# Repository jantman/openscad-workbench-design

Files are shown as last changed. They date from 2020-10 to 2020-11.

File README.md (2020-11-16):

# openscad-workbench-design

Openscad designs for my new workbench. This has been _very_ specifically sized to fit certain items.

## Final Build

There were some changes to the plans in my build. The only ones that are important should be noticeable in the photos.

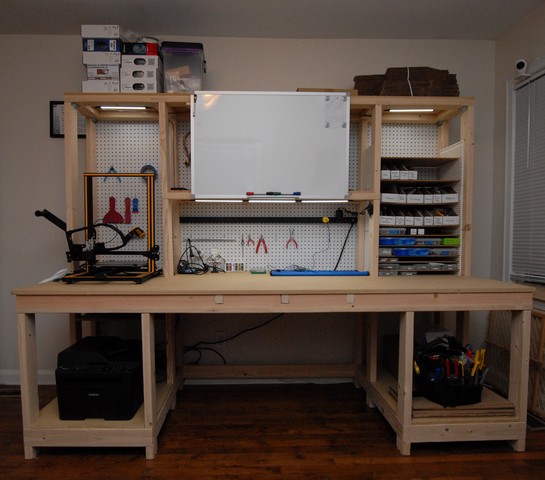
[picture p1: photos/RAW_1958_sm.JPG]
frontal photograph of finished workbench


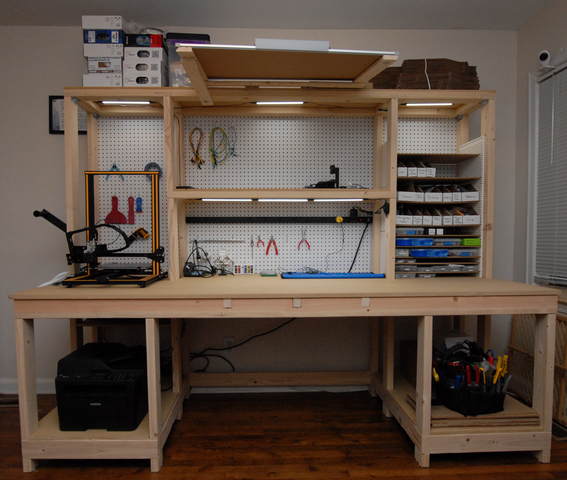
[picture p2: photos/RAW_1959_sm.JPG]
frontal photograph of finished workbench with flip-up whiteboard raised


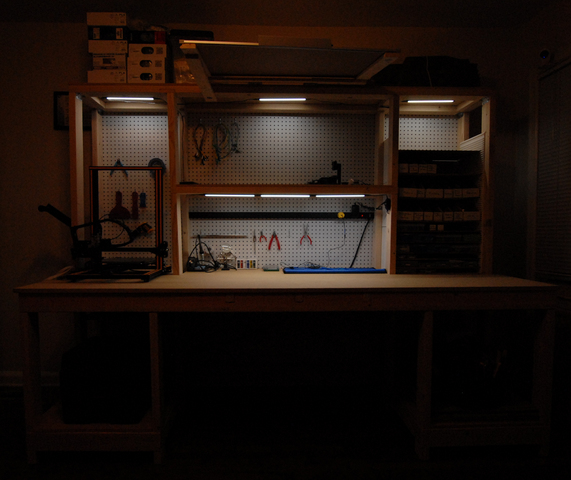
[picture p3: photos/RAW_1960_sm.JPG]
frontal photograph of finished workbench in the dark, showing build-in lights


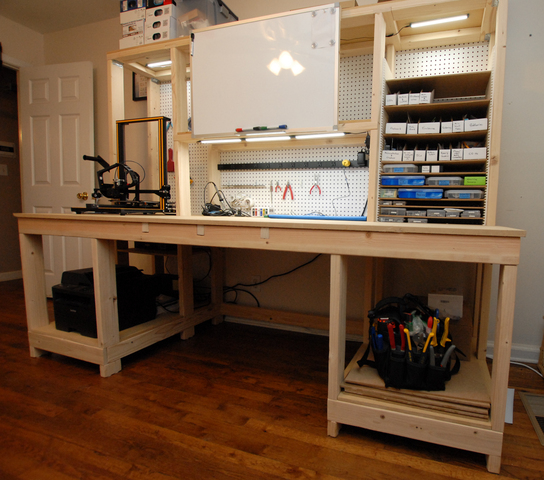
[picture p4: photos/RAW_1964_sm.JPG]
right side angle photo of finished workbench


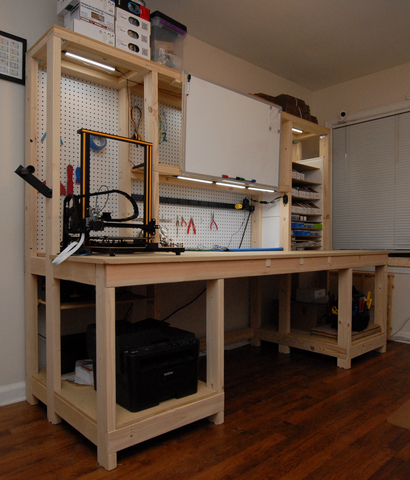
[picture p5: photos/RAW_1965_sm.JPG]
left side angle photo of finished workbench


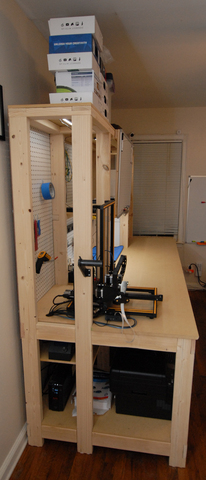
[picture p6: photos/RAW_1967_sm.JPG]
photo of left side of finished workbench


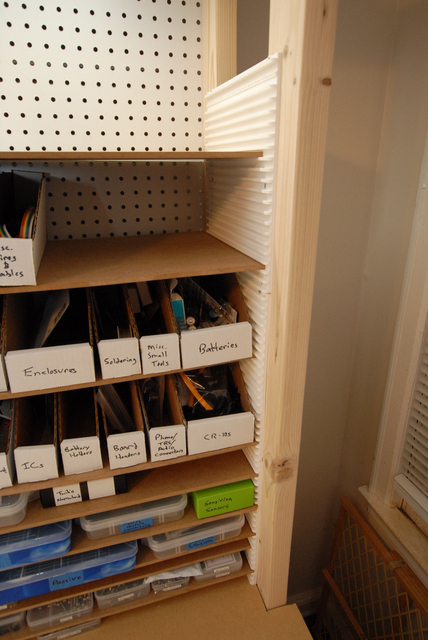
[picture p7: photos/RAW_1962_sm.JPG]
detail photo of 3d printed adjustable shelf supports


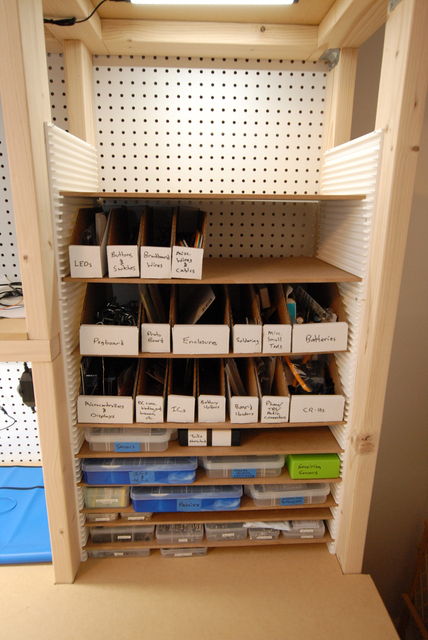
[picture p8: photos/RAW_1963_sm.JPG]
full photo of 3d printed adjustable shelf supports


## Rendered Images

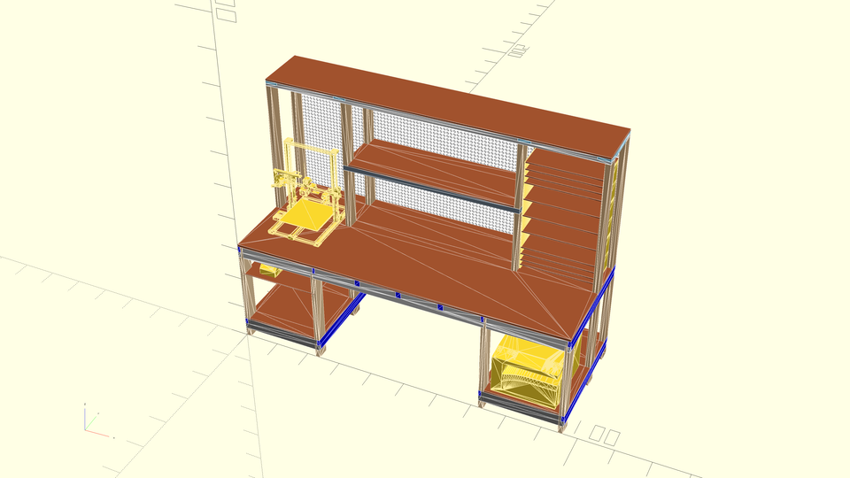
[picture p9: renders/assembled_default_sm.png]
assembled_default


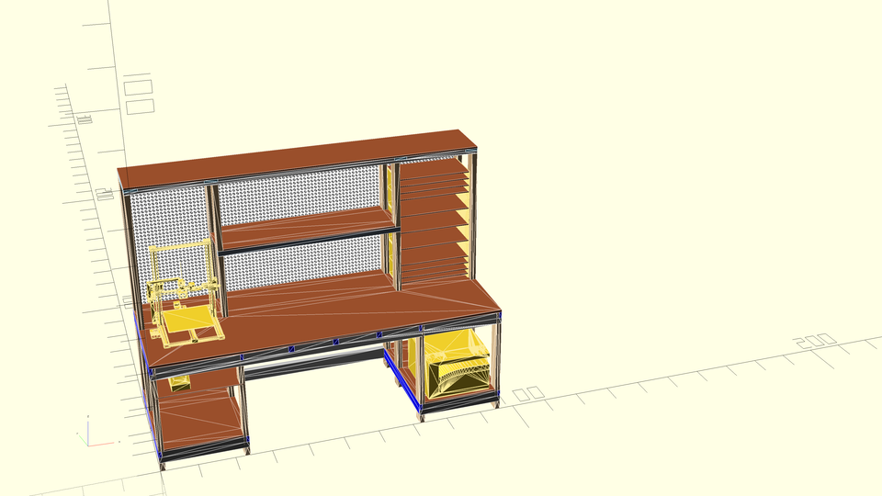
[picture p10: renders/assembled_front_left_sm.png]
assembled_front_left


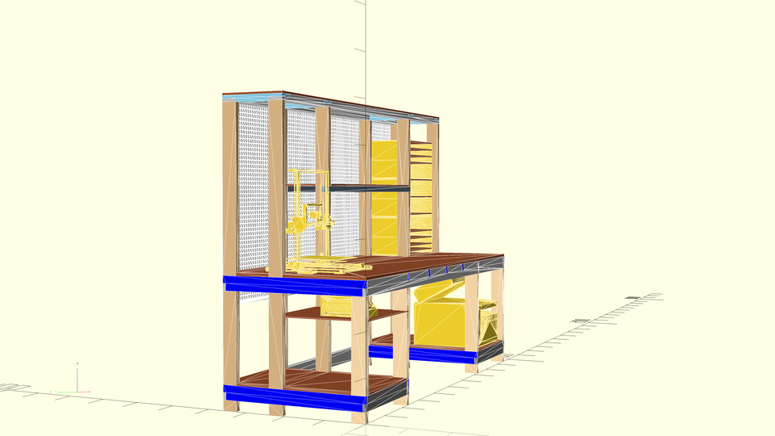
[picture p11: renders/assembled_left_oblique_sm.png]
assembled_left_oblique


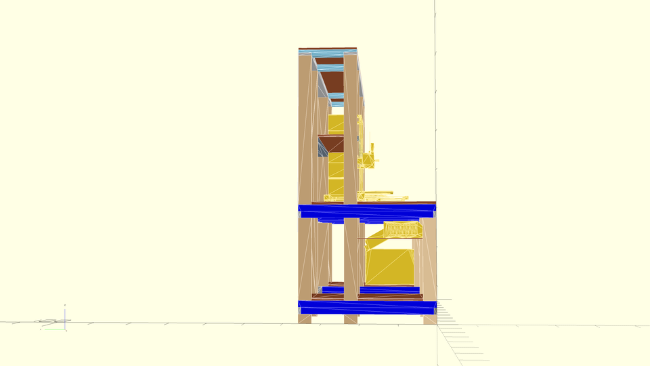
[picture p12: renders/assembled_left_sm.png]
assembled_left


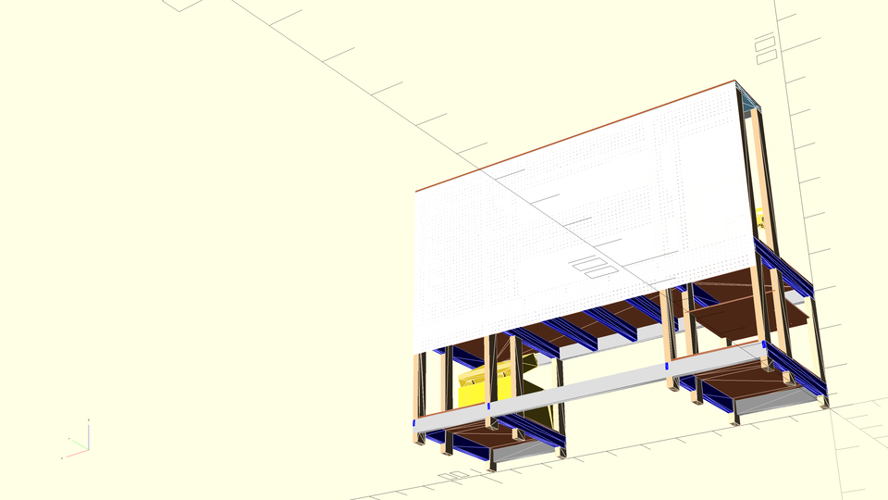
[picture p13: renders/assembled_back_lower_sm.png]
assembled_back_lower


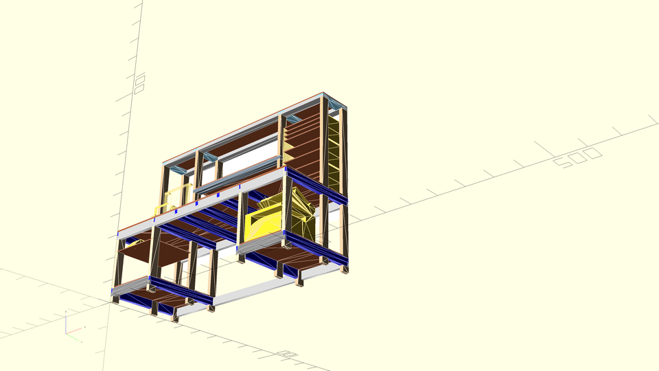
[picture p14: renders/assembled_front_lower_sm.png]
assembled_front_lower


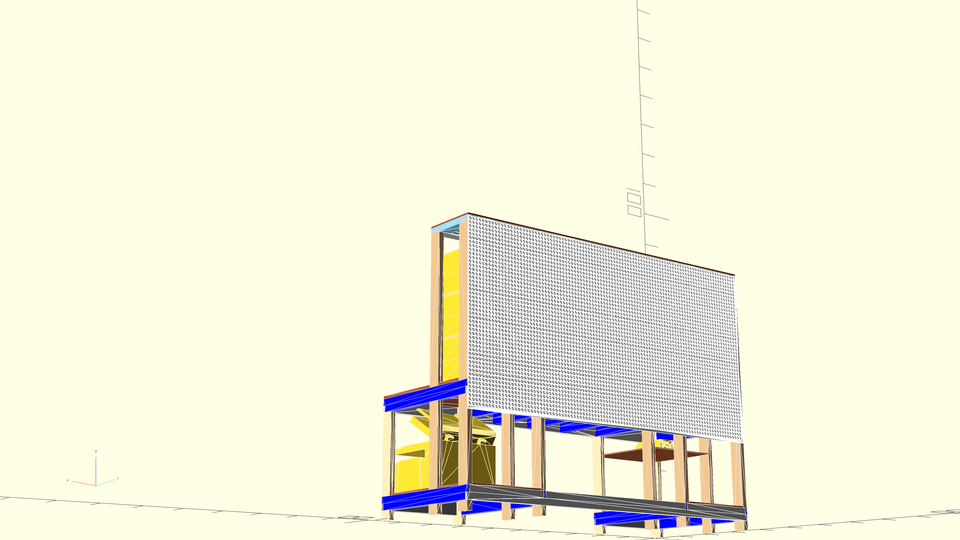
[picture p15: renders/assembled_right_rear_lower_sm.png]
assembled_right_rear_lower


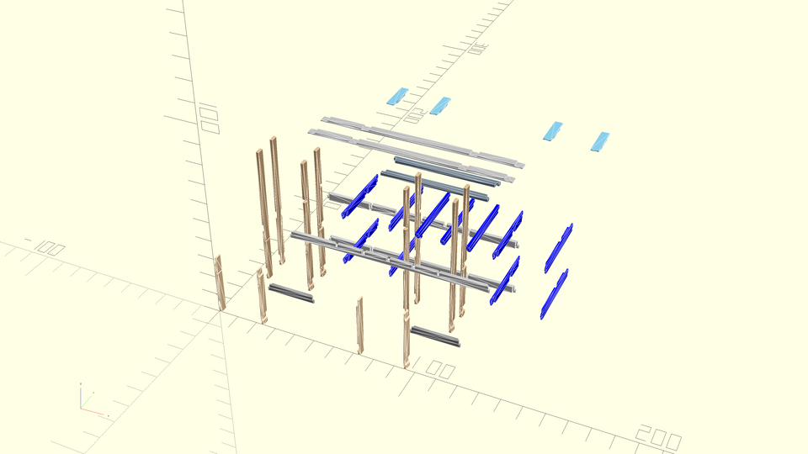
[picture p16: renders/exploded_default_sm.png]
exploded_default


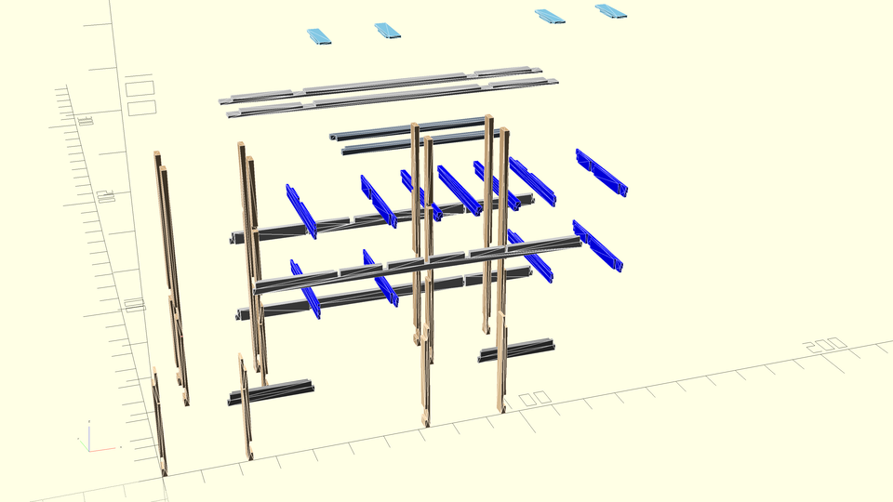
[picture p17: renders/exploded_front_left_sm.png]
exploded_front_left


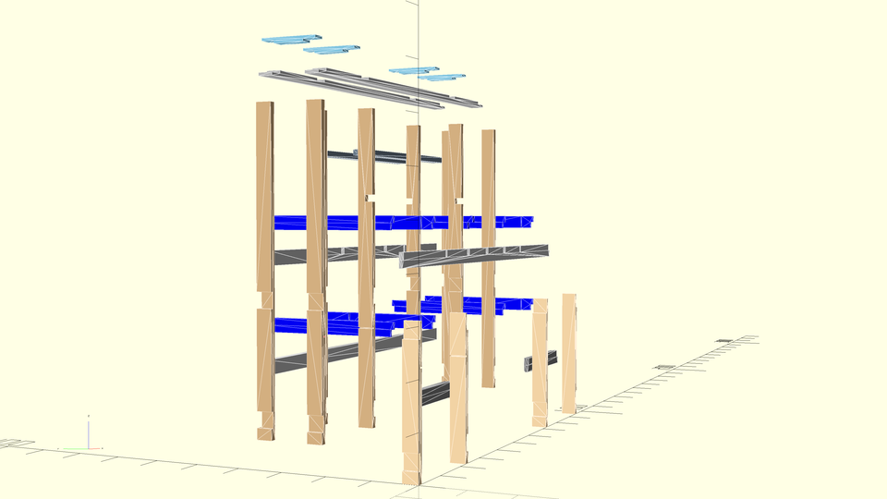
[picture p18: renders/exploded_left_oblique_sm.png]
exploded_left_oblique


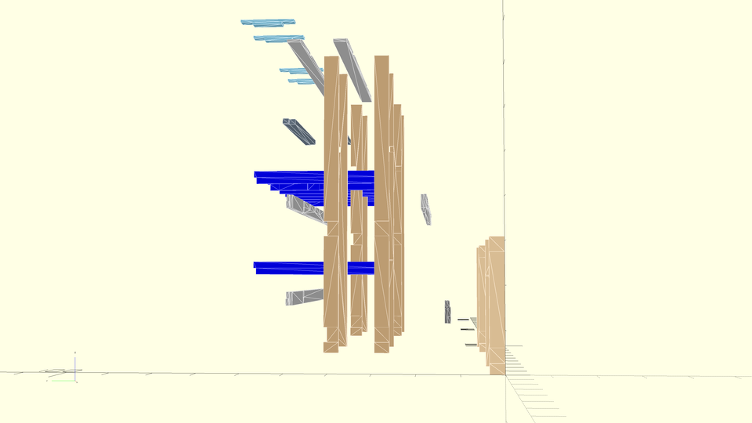
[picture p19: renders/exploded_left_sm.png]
exploded_left


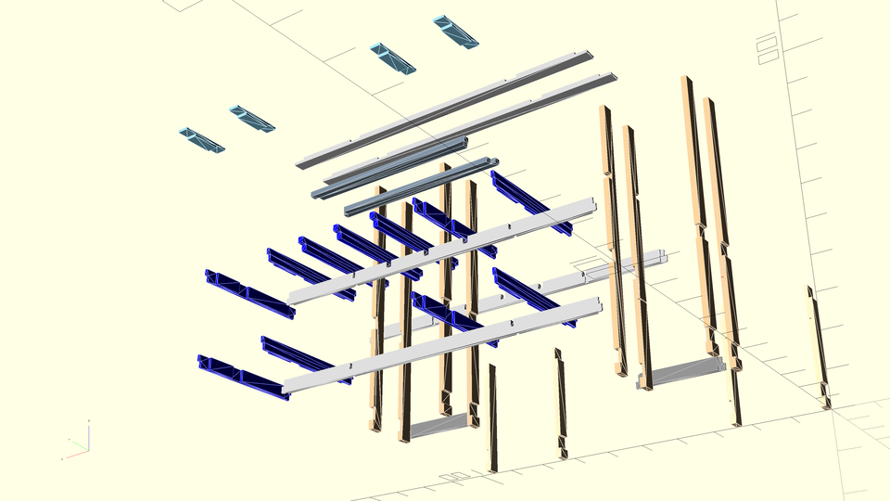
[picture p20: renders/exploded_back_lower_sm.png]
exploded_back_lower


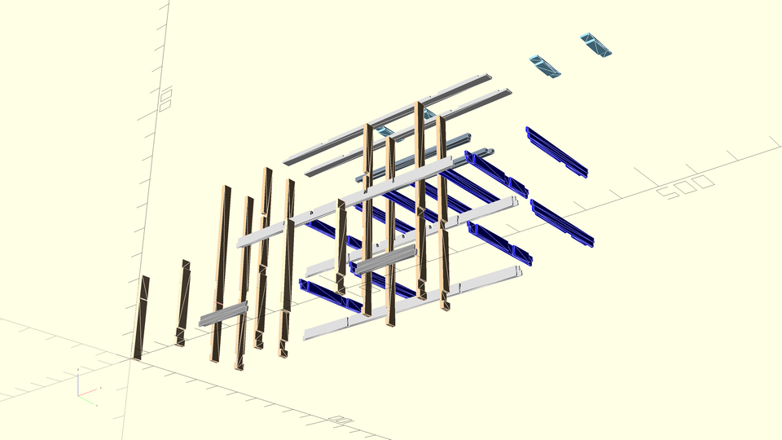
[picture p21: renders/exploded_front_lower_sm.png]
exploded_front_lower


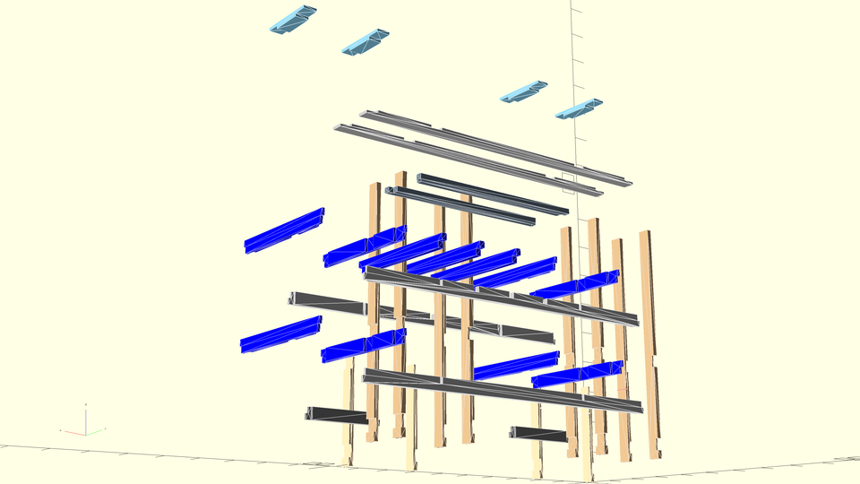
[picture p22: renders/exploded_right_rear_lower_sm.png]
exploded_right_rear_lower


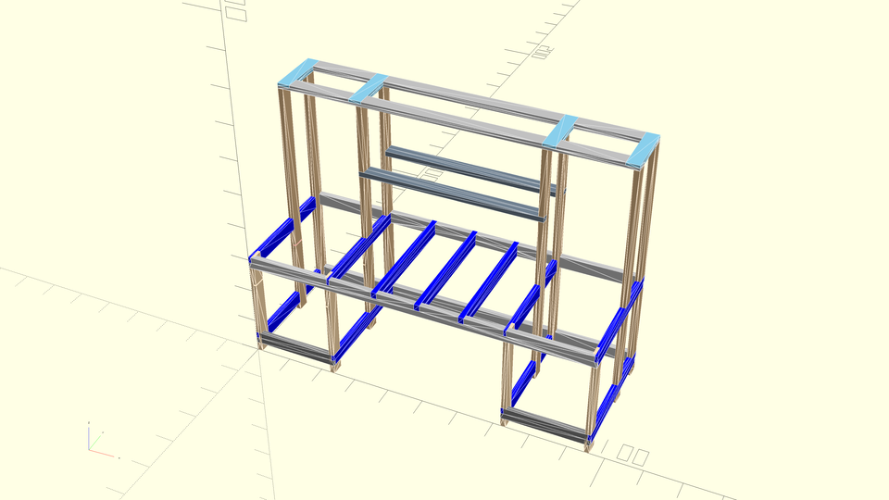
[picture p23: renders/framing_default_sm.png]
framing_default


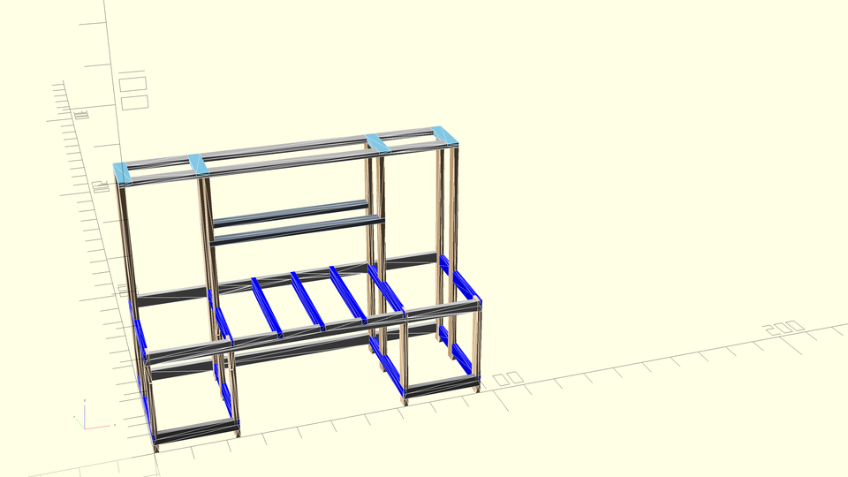
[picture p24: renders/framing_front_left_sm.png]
framing_front_left


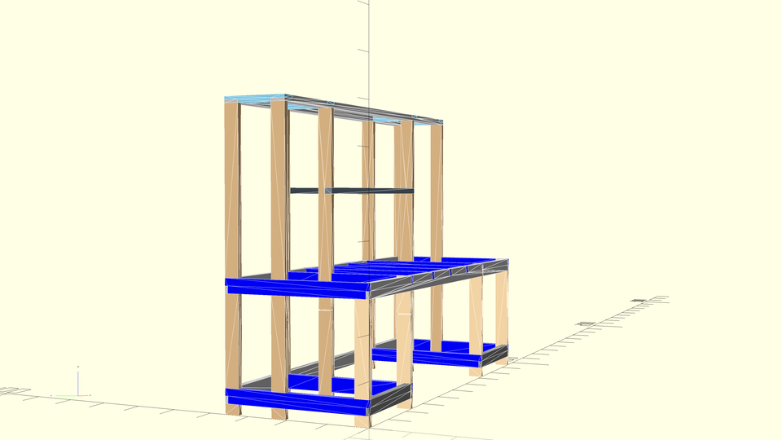
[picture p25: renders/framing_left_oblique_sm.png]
framing_left_oblique


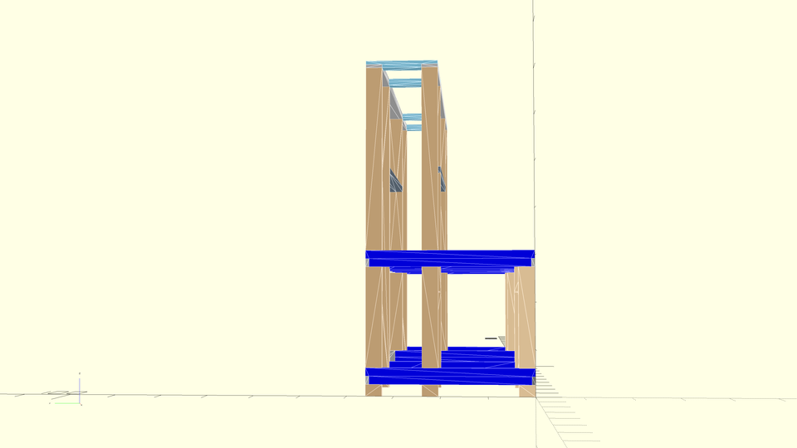
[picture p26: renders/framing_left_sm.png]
framing_left


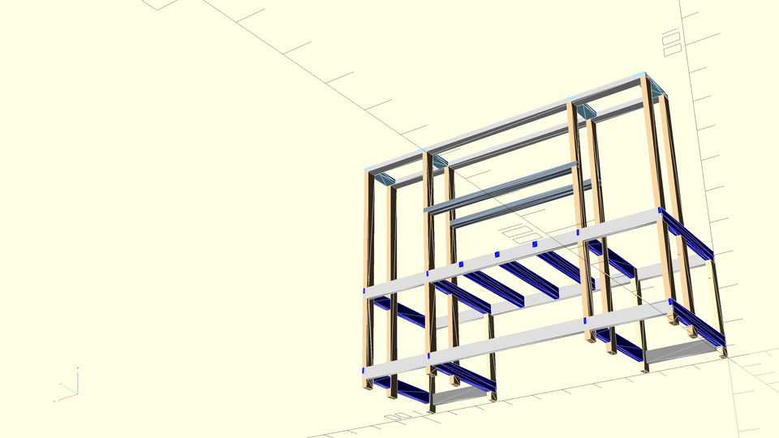
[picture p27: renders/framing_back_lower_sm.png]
framing_back_lower


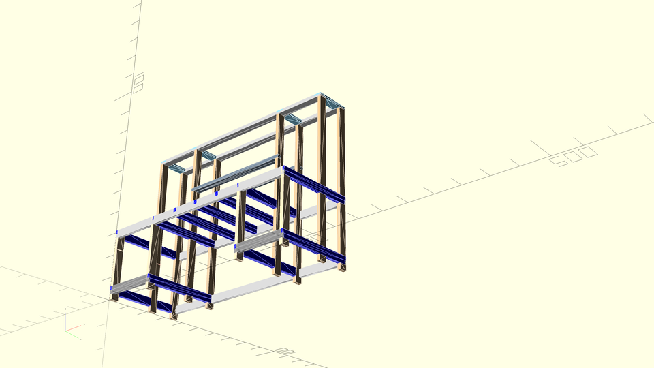
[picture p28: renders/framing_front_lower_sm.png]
framing_front_lower


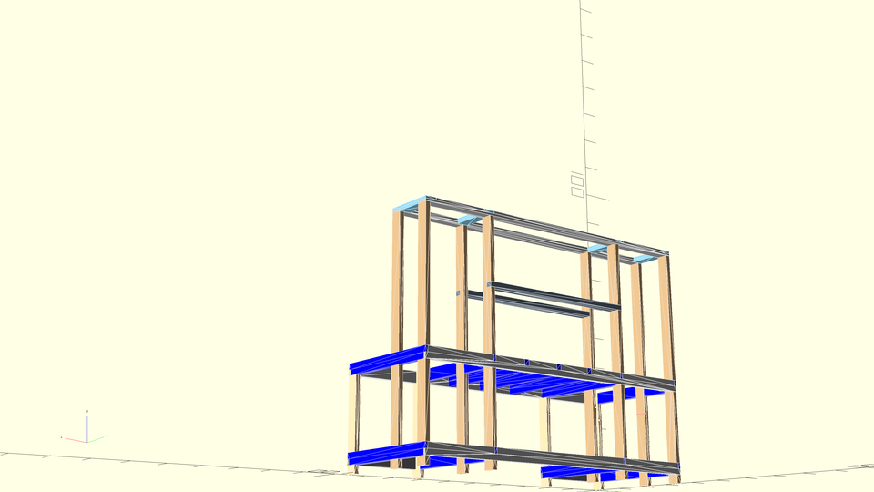
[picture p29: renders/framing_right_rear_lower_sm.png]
framing_right_rear_lower


### Shelf Supports

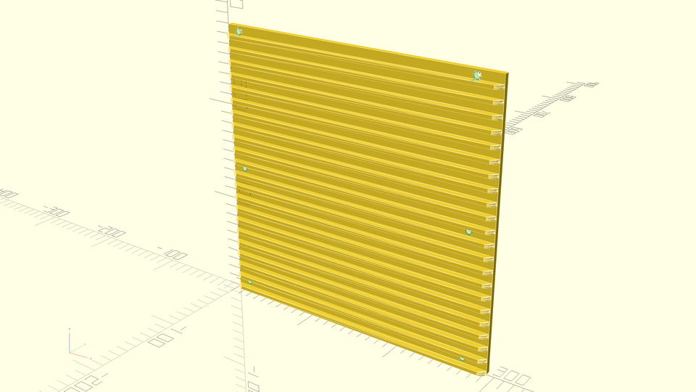
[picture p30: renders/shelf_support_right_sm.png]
shelf_support_right


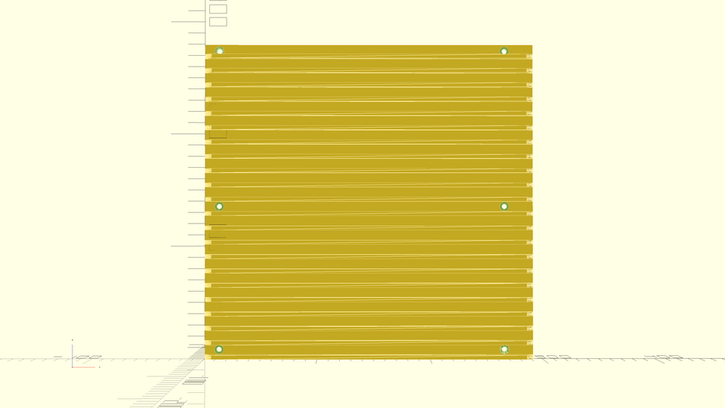
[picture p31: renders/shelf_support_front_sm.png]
shelf_support_front


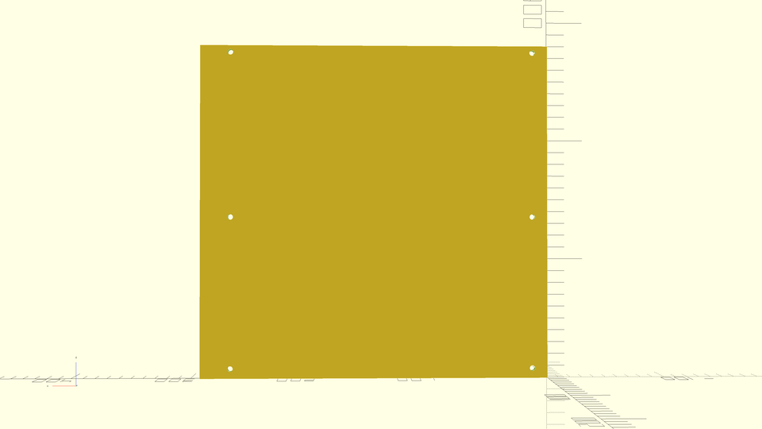
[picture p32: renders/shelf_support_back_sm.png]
shelf_support_back


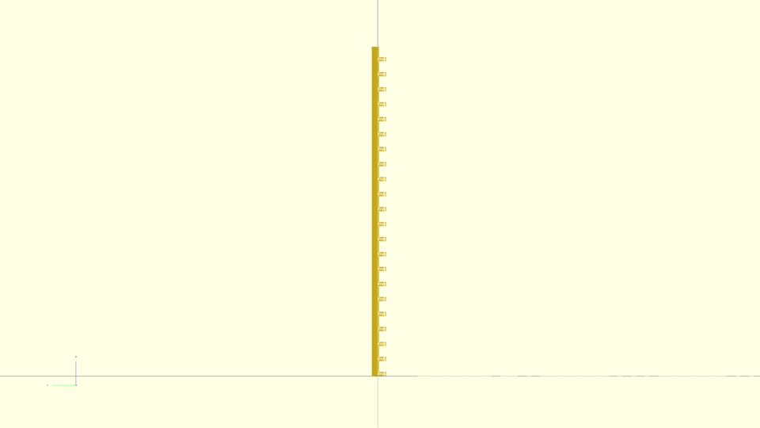
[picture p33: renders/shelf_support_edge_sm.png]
shelf_support_edge


## Parts List

* 5x 2x4x8' - long horizontal plates
* 8x 2x4x6' - rear and center legs
* 2x 2x4x51" - hutch shelf supports
* 4x 2x4x31" - front legs
* 4x 2x4x15.5" - Upper shelf supports
* 2x 2x4x2' - Lower front side short horizontal plates
* 11x 2x4x3' - Depth-wise horizontal supports (3x desktop supports, 8x lower side ties)
* 2x 2'x3' 1/2" MDF - lower shelves
* 1x 51"x15.5" 1/2" MDF - hutch shelf
* 1x 8'x3' 3/4" MDF - desktop
* 1x 8'x15.5" 1/2" MDF - top shelf
* 1x 23"x24" 1/4" MDF or plywood - left side shelf under desktop
* 1x 4'x8' pegboard, such as [this](https://www.homedepot.com/p/Pegboard-White-Panel-Common-3-16-in-x-4-ft-x-8-ft-Actual-0-155-in-x-47-7-in-x-95-7-in-486140/202189722)
* approx. 11x 12"x20.5" shelves made from [1/8" MDF](https://www.homedepot.com/p/Hardboard-Tempered-Panel-Common-1-8-in-4-ft-x-8-ft-Actual-0-115-in-x-47-7-in-x-95-7-in-832777/202189720) or [1/4" MDF](https://www.homedepot.com/p/Medium-Density-Fiberboard-Common-1-4-in-x-2-ft-x-4-ft-Actual-0-216-in-x-23-75-in-x-47-75-in-1508104/202089069) (a 4x8 sheet will make 14 shelves)
* #8 x 3/4" screws for mounting shelf supports

## Materials List

**Note:** The 1/2" MDF will fit exactly on one panel if we exclude kerf. That's what I've done, assuming the half-kerf short side will just be put on the back.

* 23x 2x4x8'
* 1x 4'x8'x3/4" MDF panel
* 1x 4'x8'x1/2" MDF panel
* 1x 2'x2'x1/4" MDF or plywood panel
* 1x 4'x8' pegboard, such as [this](https://www.homedepot.com/p/Pegboard-White-Panel-Common-3-16-in-x-4-ft-x-8-ft-Actual-0-155-in-x-47-7-in-x-95-7-in-486140/202189722)
* 1x 4'x8' [1/8" Hardboard](https://www.homedepot.com/p/Hardboard-Tempered-Panel-Common-1-8-in-4-ft-x-8-ft-Actual-0-115-in-x-47-7-in-x-95-7-in-832777/202189720) or [1/4" MDF](https://www.homedepot.com/p/Medium-Density-Fiberboard-Common-1-4-in-x-2-ft-x-4-ft-Actual-0-216-in-x-23-75-in-x-47-75-in-1508104/202089069)

## Dimensional Drawings for Fabrication and Assembly

These are tough. In short, the only way OpenSCAD can dimension drawings is if you draw, and locate, every line, arrow, and piece of text in 3D space just like any other part. I didn't know that until I'd done most of the work on this design, so I just threw in the towel on it.

[build.py](build.py) (see more below) will create ``individual_components/`` as a directory full of full-page (US Letter / 8.5x11") per-component drawings, each page containing the name, quantity, and views of all six sides. Dimensions must be added by hand, if needed. It will also create three exploded views of the framing. Because of the very poor "exploding" used, and the large number of parts, there are three exploded diagrams each showing one level of horizontal supports.

**To print** the diagrams, ensure LP is set up (``lpoptions -d PrinterName`` to set the default printer) and then just ``lp individual_components/*.png`` Since the images are already sized for the printer resolution and paper size, no scaling is needed.

## Notes

### Built Images

Running [build.py](build.py) will regenerate all rendered images in [renders/](renders/) as well as generating printable per-component views and some printable exploded diagrams (each containing a subsection of the full project, for ease of use).

### Dependencies

This code currently depends on a few STL files from another repository of mine. Rather than pull in the whole repository, which is quite large, I've included ``get_deps.sh`` which downloads the necessary files from GitHub.

### render function

According to [OpenSCAD User Manual/First Steps/Changing the color of an object - Wikibooks, open books for an open world](https://en.wikibooks.org/wiki/OpenSCAD_User_Manual/First_Steps/Changing_the_color_of_an_object) and [this mailing list post](http://forum.openscad.org/Color-in-Compile-and-Render-mode-tp4637p4639.html), color doesn't work in rendered mode, only preview. That was the case in 2013 and, as far as I can tell, is still the case in 2020. So, we can't use rendered mode, we can only use preview, because the colors are actually important.

However, in preview mode, there are usually serious issues with z-fighting between components. The fix for this seems to be to wrap each component in a [render function](https://en.wikibooks.org/wiki/OpenSCAD_User_Manual/Other_Language_Features#Render).

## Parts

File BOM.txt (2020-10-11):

      1 ECHO: "BOM ITEM: desktop width=96 depth=36 thickness=0.75"
      1 ECHO: "BOM ITEM: hutch_shelf size=51x15.5 thickness=0.5"
      1 ECHO: "BOM ITEM: leg_NOTcenter_NOTinner_NOTleft length=72 material=1.5x3.5"
      1 ECHO: "BOM ITEM: leg_NOTcenter_NOTinner_left length=72 material=1.5x3.5"
      1 ECHO: "BOM ITEM: leg_NOTcenter_inner_NOTleft length=72 material=1.5x3.5"
      1 ECHO: "BOM ITEM: leg_NOTcenter_inner_left length=72 material=1.5x3.5"
      1 ECHO: "BOM ITEM: leg_center_NOTinner_NOTleft length=72 material=1.5x3.5"
      1 ECHO: "BOM ITEM: leg_center_NOTinner_left length=72 material=1.5x3.5"
      1 ECHO: "BOM ITEM: leg_center_inner_NOTleft length=72 material=1.5x3.5"
      1 ECHO: "BOM ITEM: leg_center_inner_left length=72 material=1.5x3.5"
      1 ECHO: "BOM ITEM: long_horizontal_plate_not_top length=96 material=1.5x3.5"
      1 ECHO: "BOM ITEM: lower_left_shelf size=23x24 thickness=0.25"
      1 ECHO: "BOM ITEM: top_shelf size=96x15.5 thickness=0.5"
      2 ECHO: "BOM ITEM: hutch_shelf_support length=51 material=3.5x1.5"
      2 ECHO: "BOM ITEM: leg_short_NOTleft length=31 material=1.5x3.5"
      2 ECHO: "BOM ITEM: leg_short_left length=31 material=1.5x3.5"
      2 ECHO: "BOM ITEM: long_horizontal_plate_desktop length=96 material=1.5x3.5"
      2 ECHO: "BOM ITEM: long_horizontal_plate_top length=96 material=3.5x1.5"
      2 ECHO: "BOM ITEM: lower_shelf size=24x36 thickness=0.5"
      2 ECHO: "BOM ITEM: short_horizontal_plate length=24 material=1.5x3.5"
      2 ECHO: "BOM ITEM: upper_side_tieA length=15.5 material=3.5x1.5"
      2 ECHO: "BOM ITEM: upper_side_tieB length=15.5 material=3.5x1.5"
      3 ECHO: "BOM ITEM: desktop_support length=36 material=1.5x3.5"
      6 ECHO: "BOM ITEM: shelf_support"
      8 ECHO: "BOM ITEM: lower_side_tie length=36 material=1.5x3.5"
     11 ECHO: "BOM ITEM: adjustable_shelf width=20.6 depth=11.5 thickness=0.35"

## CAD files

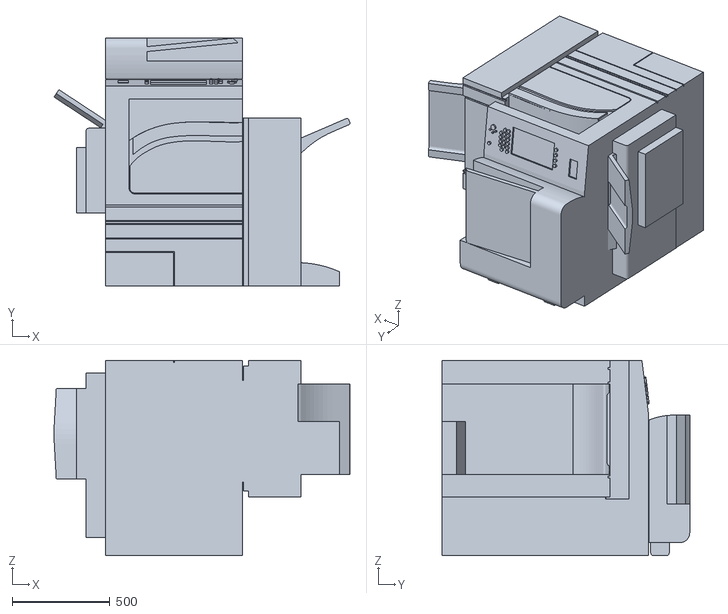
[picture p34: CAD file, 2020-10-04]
components/printer_thingiverse_494241.stl
1515.1 x 1267.0 x 1000.0

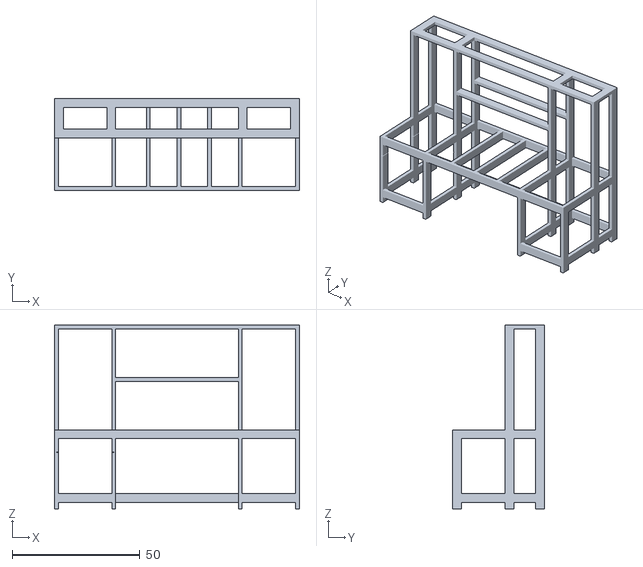
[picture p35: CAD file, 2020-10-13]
renders/framing.stl
96.0 x 36.0 x 72.0

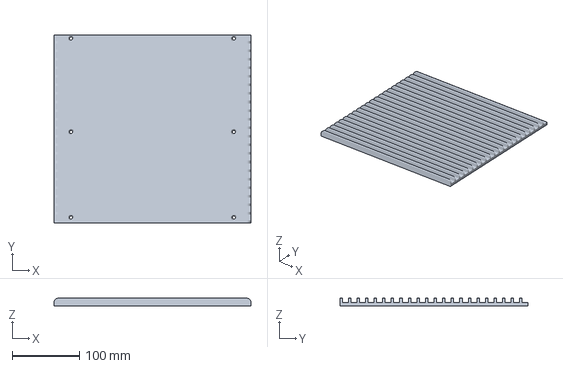
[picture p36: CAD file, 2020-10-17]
shelf_support_3d_print/CCR10S_shelf_support_HatchboxPureWhitePLA_15pctInfill.3mf
292.1 x 279.4 x 11.4 mm

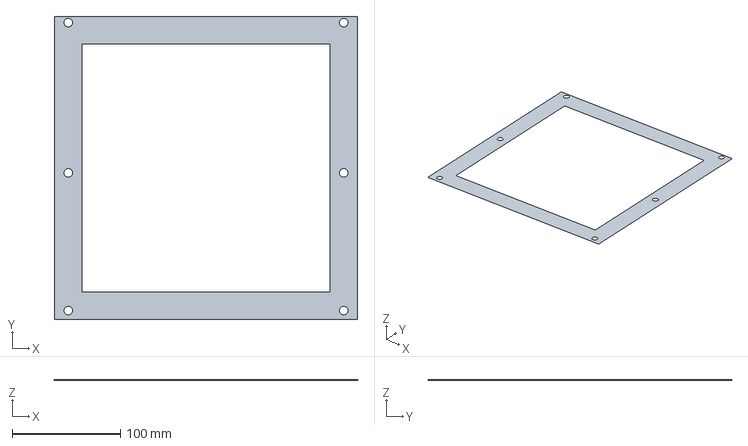
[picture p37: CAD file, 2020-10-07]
test_pieces/CCR10S_shelf_support_back.3mf
279.4 x 279.4 x 0.4 mm

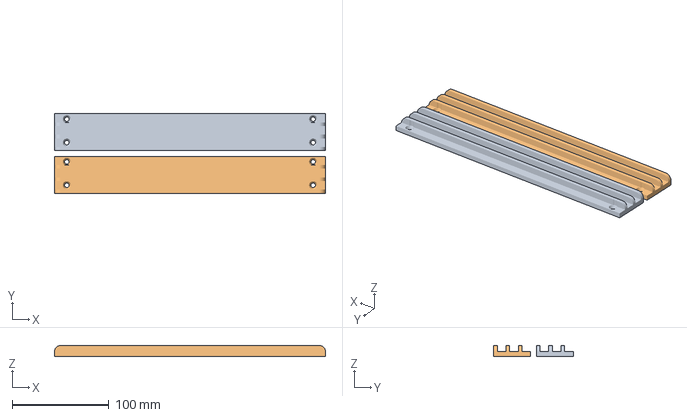
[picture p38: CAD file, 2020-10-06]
test_pieces/CCR10S_shelf_support_test.3mf
279.4 x 82.1 x 11.4 mm
shelf_support_test.stl
shelf_support_test.stl(1)

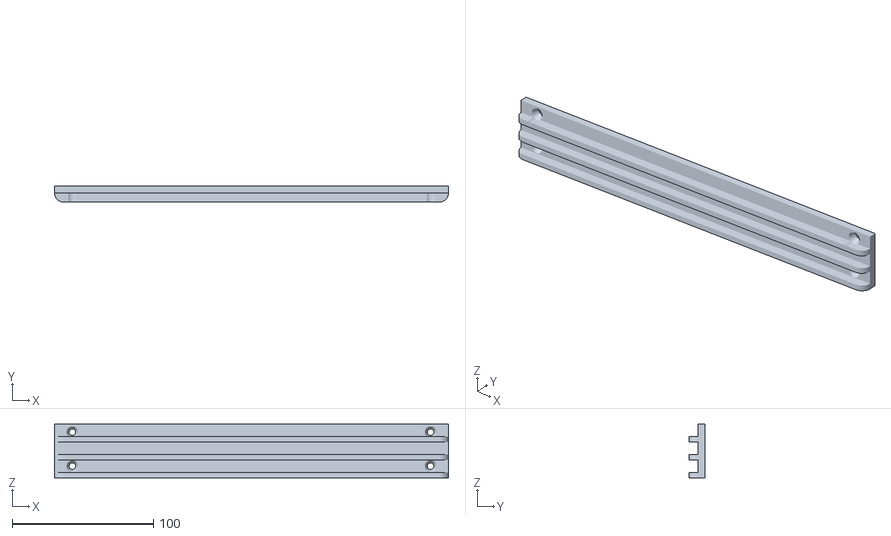
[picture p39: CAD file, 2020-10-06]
test_pieces/shelf_support_test.stl
279.4 x 11.4 x 38.1

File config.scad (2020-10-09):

// height of desktop and shelves
desktop_shelf_color="Sienna";
desktop_height=31;
desktop_thickness=0.75;
table_width=96;
table_depth=36;
shelf_thickness=0.5;
shelf_height=6;
top_shelf_height=72.5;
hutch_shelf_height=50;
left_lower_shelf_height=22;
left_lower_shelf_thickness=0.25;

// Legs
front_leg_length=desktop_height;
rear_leg_length=top_shelf_height-shelf_thickness;
leg_timber_width=1.5;
leg_timber_depth=3.5;
center_leg_timber_width=1.5;
center_leg_timber_depth=3.5;
center_leg_setback=24;

// Parts Shelves
parts_shelf_thickness = 0.35;
parts_shelf_spacing = 0.15;
parts_plate_thickness = 0.2;
parts_support_depth = 0.25;
parts_shelf_depth = 11.5;
parts_support_height = 11;
parts_shelf_width = (table_width/4)-(center_leg_timber_width*2)-(parts_plate_thickness*2);

// Plates
strut_timber_depth=1.5;
strut_timber_height=3.5;
top_shelf_timber_depth=3.5;
top_shelf_timber_height=1.5;

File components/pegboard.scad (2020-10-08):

module pegboard(height = 48, width = 96) {
    cols = height - 1;
    rows = width - 1;
    echo(str("BOM ITEM: pegboard height=", height, " width=", width));
    color("white") {
        difference(){
            cube([width,3/16,height]);
            for(row =[0:cols]){
                for(col =[0:rows]){
                    translate([0.875+col,0.25,0.875+row]){
                        rotate([90,0,0]){
                            cylinder(h=0.4, d=0.25, $fs=0.1, center=false);
                        }
                    }
                }
            }
        }
    }
}

pegboard();

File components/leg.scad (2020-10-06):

module leg(leg_length,is_center_leg,is_inner_leg,is_left = false)
{
    include <../config.scad>
    echo(str("BOM ITEM: leg length=", leg_length, " is_center_leg=", is_center_leg, " is_left=", is_left));
    render() { // see note in README about rendering
        difference() {
            cube([leg_timber_width,leg_timber_depth,leg_length],false);

            // Top rabbets
            translate([0,0,desktop_height-strut_timber_height])
            {
                // rabbet cut on short side
                if(is_center_leg == false) {
                  translate([0,(leg_timber_width-strut_timber_depth),0]){
                      cube([leg_timber_width,strut_timber_depth/2,strut_timber_height],false);
                  }
                }
                cube([strut_timber_depth/2,leg_timber_depth,strut_timber_height],false);
            }

            // Bottom rabbets
            translate([0,0,shelf_height-strut_timber_height])
            {
                // rabbet cut on short side
                if(is_center_leg == false) {
                  translate([0,(leg_timber_width-strut_timber_depth),0]){
                      cube([leg_timber_width,strut_timber_depth/2,strut_timber_height],false);
                  }
                }
                cube([strut_timber_depth/2,leg_timber_depth,strut_timber_height],false);
            }

            // rear and center legs only
            if(leg_length > desktop_height && top_shelf_timber_height >= top_shelf_timber_depth) {
              // Upper shelf rabbets for back/middle legs
              translate([0,0,leg_length-top_shelf_timber_height]){
                cube([top_shelf_timber_depth/2,leg_timber_depth,top_shelf_timber_height],false);
                cube([leg_timber_width,top_shelf_timber_depth/2,top_shelf_timber_height],false);
              }
            }
            if(leg_length > desktop_height && top_shelf_timber_height < top_shelf_timber_depth) {
              // Upper shelf rabbets for back/middle legs
              translate([0,0,leg_length-top_shelf_timber_height]){
                cube([leg_timber_width,leg_timber_depth,top_shelf_timber_height],false);
              }
            }

            // inner tall (center and rear) legs only
            if(is_inner_leg == true && leg_length > desktop_height) {
              translate([0,0,hutch_shelf_height]){
                cube([leg_timber_width,leg_timber_depth/2,strut_timber_depth],false);
              }
            }

            // shelf rabbets - left front and center legs only
            if((leg_length <= desktop_height || is_center_leg == true) && is_left == true) {
                translate([leg_timber_width/2,0,left_lower_shelf_height]){
                  #cube([leg_timber_width/2,leg_timber_depth,left_lower_shelf_thickness],false);
                }
            }
        }
    }
}

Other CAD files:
shelf_support_3d_print/shelf_support.stl
test_pieces/shelf_support_back.stl
shelf_support_3d_print/CCR10S_shelf_support_low_quality_15pct_infill.3mf
shelf_support_3d_print/CCR10S_shelf_support.3mf
components/leg_center_inner_left.scad
components/desktop.scad
components/desktop_support.scad
components/hutch_shelf.scad
components/hutch_shelf_support.scad
components/leg_NOTcenter_NOTinner_NOTleft.scad
components/leg_NOTcenter_NOTinner_left.scad
components/leg_NOTcenter_inner_NOTleft.scad
components/leg_NOTcenter_inner_left.scad
components/leg_center_NOTinner_NOTleft.scad
components/leg_center_NOTinner_left.scad
components/leg_center_inner_NOTleft.scad
components/leg_short_NOTleft.scad
components/leg_short_left.scad
components/long_horizontal_plate_desktop.scad
components/long_horizontal_plate_not_top.scad
components/long_horizontal_plate_top.scad
components/lower_shelf.scad
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

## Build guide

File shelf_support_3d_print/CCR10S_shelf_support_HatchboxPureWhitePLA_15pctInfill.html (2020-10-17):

# Print settings

Visible settings:

Job Name | CCR10S_shelf_support
Date | 16/10/2020 20:24:06
Os | Linux #1 SMP PREEMPT Thu, 17 Sep 2020 18:01:06 +0000
Cura Version | 4.7.1
Profile | empty
Quality | Standard Quality
Material Extruder : 1 | PLA
Material estimation | 325.6 g
Printing Time | 1 d 15 h 49 mn
Extruder : 1 Quality
Layer Height | 0.2 | mm
Initial Layer Height | 0.2 | mm
Line Width | 0.4 | mm
Wall Line Width | 0.4 | mm
Outer Wall Line Width | 0.4 | mm
Inner Wall(s) Line Width | 0.4 | mm
Top/Bottom Line Width | 0.4 | mm
Infill Line Width | 0.4 | mm
Skirt/Brim Line Width | 0.4 | mm
Support Line Width | 0.4 | mm
Support Interface Line Width | 0.4 | mm
Support Roof Line Width | 0.4 | mm
Support Floor Line Width | 0.4 | mm
Prime Tower Line Width | 0.4 | mm
Initial Layer Line Width | 100 | %
Extruder : 1 Shell
Wall Extruder | -1
Outer Wall Extruder | -1
Inner Wall Extruder | -1
Wall Thickness | 0.8 | mm
Wall Line Count | 2
Outer Wall Wipe Distance | 0 | mm
Top Surface Skin Extruder | -1
Top Surface Skin Layers | 0
Top/Bottom Extruder | -1
Top/Bottom Thickness | 0.8 | mm
Top Thickness | 0.8 | mm
Top Layers | 4
Bottom Thickness | 0.8 | mm
Bottom Layers | 4
Initial Bottom Layers | 4
Top/Bottom Pattern | lines
Bottom Pattern Initial Layer | lines
Connect Top/Bottom Polygons | False
Top/Bottom Line Directions | [ ]
Outer Wall Inset | 0 | mm
Optimize Wall Printing Order | True
Outer Before Inner Walls | False
Alternate Extra Wall | False
Compensate Wall Overlaps | True
Compensate Outer Wall Overlaps | False
Compensate Inner Wall Overlaps | True
Minimum Wall Flow | 0 | %
Prefer Retract | False
Fill Gaps Between Walls | everywhere
Filter Out Tiny Gaps | False
Print Thin Walls | False
Horizontal Expansion | 0 | mm
Initial Layer Horizontal Expansion | 0 | mm
Hole Horizontal Expansion | 0 | mm
Z Seam Alignment | back
Z Seam Position | back
Z Seam X | 150 | mm
Z Seam Y | 300 | mm
Seam Corner Preference | z_seam_corner_weighted
Z Seam Relative | False | mm
No Skin in Z Gaps | False
Extra Skin Wall Count | 1
Enable Ironing | False
Iron Only Highest Layer | False
Ironing Pattern | zigzag
Ironing Line Spacing | 0.1 | mm
Ironing Flow | 10 | %
Ironing Inset | 0.38 | mm
Ironing Speed | 16.6667 | mm/s
Ironing Acceleration | 500 | mm/s²
Ironing Jerk | 8 | mm/s
Skin Overlap Percentage | 10 | %
Skin Overlap | 0.04 | mm
Extruder : 1 Infill
Infill Extruder | -1
Infill Density | 15 | %
Infill Line Distance | 8 | mm
Infill Pattern | cubic
Connect Infill Lines | False
Connect Infill Polygons | False
Infill Line Directions | [ ]
Infill X Offset | 0 | mm
Infill Y Offset | 0 | mm
Randomize Infill Start | False
Infill Line Multiplier | 1
Extra Infill Wall Count | 0
Cubic Subdivision Shell | 0.4 | mm
Infill Overlap Percentage | 30 | %
Infill Overlap | 0.12 | mm
Infill Wipe Distance | 0 | mm
Infill Layer Thickness | 0.2 | mm
Gradual Infill Steps | 0
Gradual Infill Step Height | 1.5 | mm
Infill Before Walls | False
Minimum Infill Area | 0 | mm²
Infill Support | False
Infill Overhang Angle | 40 | °
Skin Removal Width | 0.8 | mm
Top Skin Removal Width | 0.8 | mm
Bottom Skin Removal Width | 0.8 | mm
Skin Expand Distance | 0.8 | mm
Top Skin Expand Distance | 0.8 | mm
Bottom Skin Expand Distance | 0.8 | mm
Maximum Skin Angle for Expansion | 90 | °
Minimum Skin Width for Expansion | 0 | mm
Skin Edge Support Thickness | 0 | mm
Skin Edge Support Layers | 0
Extruder : 1 Material
Default Printing Temperature | 190 | °C
Build Volume Temperature | 28 | °C
Printing Temperature | 190 | °C
Printing Temperature Initial Layer | 190 | °C
Initial Printing Temperature | 190 | °C
Final Printing Temperature | 190 | °C
Extrusion Cool Down Speed Modifier | 0.7 | °C/s
Default Build Plate Temperature | 55 | °C
Build Plate Temperature | 55 | °C
Build Plate Temperature Initial Layer | 55 | °C
Adhesion Tendency | 0
Surface Energy | 100 | %
Shrinkage Ratio | 0 | %
Crystalline Material | False
Anti-ooze Retracted Position | -4 | mm
Anti-ooze Retraction Speed | 5 | mm/s
Break Preparation Retracted Position | -16 | mm
Break Preparation Retraction Speed | 2 | mm/s
Break Preparation Temperature | 190 | °C
Break Retracted Position | -50 | mm
Break Retraction Speed | 25 | mm/s
Break Temperature | 50 | °C
Flush Purge Speed | 0.5
Flush Purge Length | 60
End of Filament Purge Speed | 0.5
End of Filament Purge Length | 20
Maximum Park Duration | 300
No Load Move Factor | 0.9409
Flow | 100 | %
Wall Flow | 100 | %
Outer Wall Flow | 100 | %
Inner Wall(s) Flow | 100 | %
Top/Bottom Flow | 100 | %
Top Surface Skin Flow | 100 | %
Infill Flow | 100 | %
Skirt/Brim Flow | 100 | %
Support Flow | 100 | %
Support Interface Flow | 100 | %
Support Roof Flow | 100 | %
Support Floor Flow | 100 | %
Prime Tower Flow | 100 | %
Initial Layer Flow | 100 | %
Standby Temperature | 180 | °C
Extruder : 1 Speed
Print Speed | 50 | mm/s
Infill Speed | 50 | mm/s
Wall Speed | 25 | mm/s
Outer Wall Speed | 25 | mm/s
Inner Wall Speed | 25 | mm/s
Top Surface Skin Speed | 25 | mm/s
Top/Bottom Speed | 25 | mm/s
Support Speed | 25 | mm/s
Support Infill Speed | 25 | mm/s
Support Interface Speed | 25 | mm/s
Support Roof Speed | 25 | mm/s
Support Floor Speed | 25 | mm/s
Prime Tower Speed | 25 | mm/s
Travel Speed | 150 | mm/s
Initial Layer Speed | 20 | mm/s
Initial Layer Print Speed | 20 | mm/s
Initial Layer Travel Speed | 100 | mm/s
Skirt/Brim Speed | 20 | mm/s
Z Hop Speed | 5 | mm/s
Number of Slower Layers | 2
Equalize Filament Flow | False
Maximum Speed for Flow Equalization | 150 | mm/s
Enable Acceleration Control | False
Print Acceleration | 500 | mm/s²
Infill Acceleration | 500 | mm/s²
Wall Acceleration | 500 | mm/s²
Outer Wall Acceleration | 500 | mm/s²
Inner Wall Acceleration | 500 | mm/s²
Top Surface Skin Acceleration | 500 | mm/s²
Top/Bottom Acceleration | 500 | mm/s²
Support Acceleration | 500 | mm/s²
Support Infill Acceleration | 500 | mm/s²
Support Interface Acceleration | 500 | mm/s²
Support Roof Acceleration | 500 | mm/s²
Support Floor Acceleration | 500 | mm/s²
Prime Tower Acceleration | 500 | mm/s²
Travel Acceleration | 500 | mm/s²
Initial Layer Acceleration | 500 | mm/s²
Initial Layer Print Acceleration | 500 | mm/s²
Initial Layer Travel Acceleration | 500 | mm/s²
Skirt/Brim Acceleration | 500 | mm/s²
Enable Jerk Control | False
Print Jerk | 8 | mm/s
Infill Jerk | 8 | mm/s
Wall Jerk | 8 | mm/s
Outer Wall Jerk | 8 | mm/s
Inner Wall Jerk | 8 | mm/s
Top Surface Skin Jerk | 8 | mm/s
Top/Bottom Jerk | 8 | mm/s
Support Jerk | 8 | mm/s
Support Infill Jerk | 8 | mm/s
Support Interface Jerk | 8 | mm/s
Support Roof Jerk | 8 | mm/s
Support Floor Jerk | 8 | mm/s
Prime Tower Jerk | 8 | mm/s
Travel Jerk | 8 | mm/s
Initial Layer Jerk | 8 | mm/s
Initial Layer Print Jerk | 8 | mm/s
Initial Layer Travel Jerk | 8 | mm/s
Skirt/Brim Jerk | 8 | mm/s
Extruder : 1 Travel
Enable Retraction | True
Retract at Layer Change | False
Retraction Distance | 5 | mm
Retraction Speed | 45 | mm/s
Retraction Retract Speed | 45 | mm/s
Retraction Prime Speed | 45 | mm/s
Retraction Extra Prime Amount | 0 | mm³
Retraction Minimum Travel | 1.5 | mm
Maximum Retraction Count | 100
Minimum Extrusion Distance Window | 10 | mm
Limit Support Retractions | True
Combing Mode | noskin
Max Comb Distance With No Retract | 30 | mm
Retract Before Outer Wall | True
Avoid Printed Parts When Traveling | True
Avoid Supports When Traveling | True
Travel Avoid Distance | 0.625 | mm
Layer Start X | 0 | mm
Layer Start Y | 0 | mm
Z Hop When Retracted | False
Z Hop Only Over Printed Parts | False
Z Hop Height | 0.2 | mm
Z Hop After Extruder Switch | True
Z Hop After Extruder Switch Height | 0.2 | mm
Extruder : 1 Cooling
Enable Print Cooling | True
Fan Speed | 100 | %
Regular Fan Speed | 100 | %
Maximum Fan Speed | 100 | %
Regular/Maximum Fan Speed Threshold | 10 | s
Initial Fan Speed | 0 | %
Regular Fan Speed at Height | 0.6 | mm
Regular Fan Speed at Layer | 4
Minimum Layer Time | 10 | s
Minimum Speed | 10 | mm/s
Lift Head | False
Support
Generate Support | False
Support Extruder | 0
Support Infill Extruder | 0
First Layer Support Extruder | 0
Support Interface Extruder | 0
Support Roof Extruder | 0
Support Floor Extruder | 0
Support Structure | normal
Tree Support Branch Angle | 40 | °
Tree Support Branch Distance | 1 | mm
Tree Support Branch Diameter | 2 | mm
Tree Support Branch Diameter Angle | 5 | °
Tree Support Collision Resolution | 0.2 | mm
Support Placement | everywhere
Support Overhang Angle | 45 | °
Support Pattern | zigzag
Support Wall Line Count | 1
Connect Support Lines | False
Connect Support ZigZags | True
Support Density | 20 | %
Support Line Distance | 2 | mm
Initial Layer Support Line Distance | 2 | mm
Support Infill Line Directions | [ ]
Enable Support Brim | True
Support Brim Width | 4 | mm
Support Brim Line Count | 10
Support Z Distance | 0.2 | mm
Support Top Distance | 0.2 | mm
Support Bottom Distance | 0.2 | mm
Support X/Y Distance | 0.8 | mm
Support Distance Priority | xy_overrides_z
Minimum Support X/Y Distance | 0.4 | mm
Support Stair Step Height | 0.3 | mm
Support Stair Step Maximum Width | 5 | mm
Support Stair Step Minimum Slope Angle | 10 | °
Support Join Distance | 2 | mm
Support Horizontal Expansion | 0 | mm
Support Infill Layer Thickness | 0.2 | mm
Gradual Support Infill Steps | 0
Gradual Support Infill Step Height | 1 | mm
Minimum Support Area | 2 | mm²
Enable Support Interface | True
Enable Support Roof | True
Enable Support Floor | True
Support Interface Thickness | 0.8 | mm
Support Roof Thickness | 0.8 | mm
Support Floor Thickness | 0.8 | mm
Support Interface Resolution | 0.2 | mm
Support Interface Density | 33.333 | %
Support Roof Density | 33.333 | %
Support Roof Line Distance | 2.4 | mm
Support Floor Density | 33.333 | %
Support Floor Line Distance | 2.4 | mm
Support Interface Pattern | grid
Support Roof Pattern | grid
Support Floor Pattern | grid
Minimum Support Interface Area | 10 | mm²
Minimum Support Roof Area | 10 | mm²
Minimum Support Floor Area | 10 | mm²
Support Interface Horizontal Expansion | 0 | mm
Support Roof Horizontal Expansion | 0 | mm
Support Floor Horizontal Expansion | 0 | mm
Support Interface Line Directions | [ ]
Support Roof Line Directions | [ ]
Support Floor Line Directions | [ ]
Fan Speed Override | False
Supported Skin Fan Speed | 100 | %
Use Towers | False
Tower Diameter | 3 | mm
Maximum Tower-Supported Diameter | 3 | mm
Tower Roof Angle | 65 | °
Drop Down Support Mesh | True
Scene Has Support Meshes | False
Build Plate Adhesion
Enable Prime Blob | False
Extruder Prime X Position | 0 | mm
Extruder Prime Y Position | 0 | mm
Build Plate Adhesion Type | none
Build Plate Adhesion Extruder | 0
Skirt Line Count | 3
Skirt Distance | 10 | mm
Skirt/Brim Minimum Length | 250 | mm
Brim Width | 8 | mm
Brim Line Count | 20
Brim Distance | 0 | mm
Brim Replaces Support | False
Brim Only on Outside | True
Raft Extra Margin | 15 | mm
Raft Smoothing | 5 | mm
Raft Air Gap | 0.3 | mm
Initial Layer Z Overlap | 0.15 | mm
Raft Top Layers | 2
Raft Top Layer Thickness | 0.2 | mm
Raft Top Line Width | 0.4 | mm
Raft Top Spacing | 0.4 | mm
Raft Middle Thickness | 0.3 | mm
Raft Middle Line Width | 0.8 | mm
Raft Middle Spacing | 1 | mm
Raft Base Thickness | 0.24 | mm
Raft Base Line Width | 0.8 | mm
Raft Base Line Spacing | 1.6 | mm
Raft Print Speed | 25 | mm/s
Raft Top Print Speed | 25 | mm/s
Raft Middle Print Speed | 18.75 | mm/s
Raft Base Print Speed | 18.75 | mm/s
Raft Print Acceleration | 500 | mm/s²
Raft Top Print Acceleration | 500 | mm/s²
Raft Middle Print Acceleration | 500 | mm/s²
Raft Base Print Acceleration | 500 | mm/s²
Raft Print Jerk | 8 | mm/s
Raft Top Print Jerk | 8 | mm/s
Raft Middle Print Jerk | 8 | mm/s
Raft Base Print Jerk | 8 | mm/s
Raft Fan Speed | 0 | %
Raft Top Fan Speed | 0 | %
Raft Middle Fan Speed | 0 | %
Raft Base Fan Speed | 0 | %
Extruder : 1 Mesh Fixes
Union Overlapping Volumes | True
Remove All Holes | False
Extensive Stitching | False
Keep Disconnected Faces | False
Merged Meshes Overlap | 0.15 | mm
Remove Mesh Intersection | False
Alternate Mesh Removal | True
Remove Empty First Layers | True
Maximum Resolution | 0.05 | mm
Maximum Travel Resolution | 0.05 | mm
Maximum Deviation | 0.025 | mm
Special Modes
Print Sequence | all_at_once
Infill Mesh | False
Mesh Processing Rank | 0
Cutting Mesh | False
Mold | False
Minimal Mold Width | 5 | mm
Mold Roof Height | 0.5 | mm
Mold Angle | 40 | °
Support Mesh | False
Anti Overhang Mesh | False
Surface Mode | normal
Spiralize Outer Contour | False
Smooth Spiralized Contours | True
Relative Extrusion | False
Experimental
Slicing Tolerance | middle
Top Surface Skin Line Width | 0.4 | mm
Top Surface Skin Pattern | lines
Top Surface Skin Line Directions | [ ]
Infill Travel Optimization | False
Auto Temperature | False
Flow Temperature Graph | [[3.5,200],[7.0,240]] | [[mm³,°C]]
Minimum Polygon Circumference | 1 | mm
Break Up Support In Chunks | False
Support Chunk Size | 20 | mm
Support Chunk Line Count | 10
Enable Draft Shield | False
Draft Shield X/Y Distance | 10 | mm
Draft Shield Limitation | full
Draft Shield Height | 10 | mm
Make Overhang Printable | False
Maximum Model Angle | 50 | °
Enable Coasting | False
Coasting Volume | 0.064 | mm³
Minimum Volume Before Coasting | 0.8 | mm³
Coasting Speed | 90 | %
Cross 3D Pocket Size | 8 | mm
Cross Infill Density Image
Cross Fill Density Image for Support
Enable Conical Support | False
Conical Support Angle | 30 | °
Conical Support Minimum Width | 5 | mm
Fuzzy Skin | False
Fuzzy Skin Outside Only | False
Fuzzy Skin Thickness | 0.3 | mm
Fuzzy Skin Density | 1.25 | 1/mm
Fuzzy Skin Point Distance | 0.8 | mm
Flow Rate Compensation Max Extrusion Offset | 0 | mm
Flow Rate Compensation Factor | 100 | %
Wire Printing | False
WP Connection Height | 3 | mm
WP Roof Inset Distance | 3 | mm
WP Speed | 5 | mm/s
WP Bottom Printing Speed | 5 | mm/s
WP Upward Printing Speed | 5 | mm/s
WP Downward Printing Speed | 5 | mm/s
WP Horizontal Printing Speed | 5 | mm/s
WP Flow | 100 | %
WP Connection Flow | 100 | %
WP Flat Flow | 100 | %
WP Top Delay | 0 | s
WP Bottom Delay | 0 | s
WP Flat Delay | 0.1 | s
WP Ease Upward | 0.3 | mm
WP Knot Size | 0.6 | mm
WP Fall Down | 0.5 | mm
WP Drag Along | 0.6 | mm
WP Strategy | compensate
WP Straighten Downward Lines | 20 | %
WP Roof Fall Down | 2 | mm
WP Roof Drag Along | 0.8 | mm
WP Roof Outer Delay | 0.2 | s
WP Nozzle Clearance | 1 | mm
Use Adaptive Layers | False
Adaptive Layers Maximum Variation | 0.04 | mm
Adaptive Layers Variation Step Size | 0.04 | mm
Adaptive Layers Topography Size | 0.2 | mm
Overhanging Wall Angle | 90 | °
Overhanging Wall Speed | 100 | %
Enable Bridge Settings | False
Minimum Bridge Wall Length | 5 | mm
Bridge Skin Support Threshold | 50 | %
Bridge Sparse Infill Max Density | 0 | %
Bridge Wall Coasting | 100 | %
Bridge Wall Speed | 12.5 | mm/s
Bridge Wall Flow | 50 | %
Bridge Skin Speed | 12.5 | mm/s
Bridge Skin Flow | 60 | %
Bridge Skin Density | 100 | %
Bridge Fan Speed | 100 | %
Bridge Has Multiple Layers | True
Bridge Second Skin Speed | 12.5 | mm/s
Bridge Second Skin Flow | 100 | %
Bridge Second Skin Density | 75 | %
Bridge Second Skin Fan Speed | 0 | %
Bridge Third Skin Speed | 12.5 | mm/s
Bridge Third Skin Flow | 110 | %
Bridge Third Skin Density | 80 | %
Bridge Third Skin Fan Speed | 0 | %
Wipe Nozzle Between Layers | False
Material Volume Between Wipes | 10 | mm³
Wipe Retraction Enable | True
Wipe Retraction Distance | 5 | mm
Wipe Retraction Extra Prime Amount | 0 | mm³
Wipe Retraction Speed | 45 | mm/s
Wipe Retraction Retract Speed | 45 | mm/s
Wipe Retraction Prime Speed | 45 | mm/s
Wipe Pause | 0 | s
Wipe Z Hop | False
Wipe Z Hop Height | 0.2 | mm
Wipe Hop Speed | 5 | mm/s
Wipe Brush X Position | 100 | mm
Wipe Repeat Count | 5
Wipe Move Distance | 20 | mm
Small Hole Max Size | 0 | mm
Small Feature Max Length | 0 | mm
Small Feature Speed | 50 | %
Small Feature Initial Layer Speed | 50 | %
Machine
Machine Type | Creality CR-10S
Show Machine Variants | False

Start G-code

M201 X500.00 Y500.00 Z100.00 E5000.00 ;Setup machine max acceleration M203 X500.00 Y500.00 Z10.00 E50.00 ;Setup machine max feedrate M204 P500.00 R1000.00 T500.00 ;Setup Print/Retract/Travel acceleration M205 X8.00 Y8.00 Z0.40 E5.00 ;Setup Jerk M220 S100 ;Reset Feedrate M221 S100 ;Reset Flowrate G28 ;Home G92 E0 ;Reset Extruder G1 Z2.0 F3000 ;Move Z Axis up G1 X10.1 Y20 Z0.28 F5000.0 ;Move to start position G1 X10.1 Y200.0 Z0.28 F1500.0 E15 ;Draw the first line G1 X10.4 Y200.0 Z0.28 F5000.0 ;Move to side a little G1 X10.4 Y20 Z0.28 F1500.0 E30 ;Draw the second line G92 E0 ;Reset Extruder G1 Z2.0 F3000 ;Move Z Axis up
End G-code | G91 ;Relative positioning G1 E-2 F2700 ;Retract a bit G1 E-2 Z0.2 F2400 ;Retract and raise Z G1 X5 Y5 F3000 ;Wipe out G1 Z10 ;Raise Z more G90 ;Absolute positionning G1 X0 Y{machine_depth} ;Present print M106 S0 ;Turn-off fan M104 S0 ;Turn-off hotend M140 S0 ;Turn-off bed M84 X Y E ;Disable all steppers but Z
Material GUID | 0ff92885-617b-4144-a03c-9989872454bc
Diameter | 1.75 | mm
Wait for Build Plate Heatup | True
Wait for Nozzle Heatup | True
Include Material Temperatures | True
Include Build Plate Temperature | True
Machine Width | 300
Machine Depth | 300
Build Plate Shape | rectangular
Build Plate Material | glass
Machine Height | 400
Has Heated Build Plate | True
Has Build Volume Temperature Stabilization | False
Always Write Active Tool | False
Is Center Origin | False
Number of Extruders | 1
Number of Extruders That Are Enabled | 1
Outer Nozzle Diameter | 1 | mm
Nozzle Length | 3 | mm
Nozzle Angle | 45 | °
Heat Zone Length | 16 | mm
Enable Nozzle Temperature Control | True
Heat Up Speed | 2 | °C/s
Cool Down Speed | 2 | °C/s
Minimal Time Standby Temperature | 50 | s
G-code Flavor | RepRap (Marlin/Sprinter)
Firmware Retraction | False
Extruders Share Heater | False
Disallowed Areas | []
Nozzle Disallowed Areas | []
Machine Head & Fan Polygon | [[-26, 34], [-26, -32], [32, -32], [32, 34]]
Gantry Height | 25
Nozzle ID | unknown
Nozzle Diameter | 0.4 | mm
Offset with Extruder | True
Extruder Prime Z Position | 0 | mm
Absolute Extruder Prime Position | False
Maximum Speed X | 500 | mm/s
Maximum Speed Y | 500 | mm/s
Maximum Speed Z | 10 | mm/s
Maximum Feedrate | 50 | mm/s
Maximum Acceleration X | 500 | mm/s²
Maximum Acceleration Y | 500 | mm/s²
Maximum Acceleration Z | 100 | mm/s²
Maximum Filament Acceleration | 5000 | mm/s²
Default Acceleration | 500 | mm/s²
Default X-Y Jerk | 10 | mm/s
Default Z Jerk | 0.4 | mm/s
Default Filament Jerk | 5 | mm/s
Steps per Millimeter (X) | 50
Steps per Millimeter (Y) | 50
Steps per Millimeter (Z) | 50
Steps per Millimeter (E) | 1600
X Endstop in Positive Direction | False
Y Endstop in Positive Direction | False
Z Endstop in Positive Direction | True
Minimum Feedrate | 0 | mm/s
Feeder Wheel Diameter | 10 | mm
Extruder : 1 Machine
Extruder | 0
Nozzle ID | unknown
Nozzle Diameter | 0.4 | mm
Nozzle X Offset | 0 | mm
Nozzle Y Offset | 0 | mm
Extruder Start G-Code
Extruder Start Position Absolute | False
Extruder Start Position X | 0 | mm
Extruder Start Position Y | 0 | mm
Extruder End G-Code
Extruder End Position Absolute | False
Extruder End Position X | 0 | mm
Extruder End Position Y | 0 | mm
Extruder Prime Z Position | 0 | mm
Extruder Print Cooling Fan | 0

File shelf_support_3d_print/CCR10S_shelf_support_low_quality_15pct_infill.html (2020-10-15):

# Print settings

Visible settings:

Job Name | CCR10S_shelf_support_low_quality_15pct_infill
Date | 15/10/2020 06:28:59
Os | Linux #1 SMP PREEMPT Thu, 17 Sep 2020 18:01:06 +0000
Cura Version | 4.7.1
Profile | empty
Quality | Low Quality
Material Extruder : 1 | PLA
Material estimation | 378.6 g
Printing Time | 1 d 10 h 6 mn
Extruder : 1 Quality
Layer Height | 0.28 | mm
Initial Layer Height | 0.28 | mm
Line Width | 0.4 | mm
Wall Line Width | 0.4 | mm
Outer Wall Line Width | 0.4 | mm
Inner Wall(s) Line Width | 0.4 | mm
Top/Bottom Line Width | 0.4 | mm
Infill Line Width | 0.4 | mm
Skirt/Brim Line Width | 0.4 | mm
Support Line Width | 0.4 | mm
Support Interface Line Width | 0.4 | mm
Support Roof Line Width | 0.4 | mm
Support Floor Line Width | 0.4 | mm
Prime Tower Line Width | 0.4 | mm
Initial Layer Line Width | 100 | %
Extruder : 1 Shell
Wall Extruder | -1
Outer Wall Extruder | -1
Inner Wall Extruder | -1
Wall Thickness | 0.8 | mm
Wall Line Count | 2
Outer Wall Wipe Distance | 0 | mm
Top Surface Skin Extruder | -1
Top Surface Skin Layers | 0
Top/Bottom Extruder | -1
Top/Bottom Thickness | 1.12 | mm
Top Thickness | 1.12 | mm
Top Layers | 4
Bottom Thickness | 1.12 | mm
Bottom Layers | 4
Initial Bottom Layers | 4
Top/Bottom Pattern | lines
Bottom Pattern Initial Layer | lines
Connect Top/Bottom Polygons | False
Top/Bottom Line Directions | [ ]
Outer Wall Inset | 0 | mm
Optimize Wall Printing Order | True
Outer Before Inner Walls | False
Alternate Extra Wall | False
Compensate Wall Overlaps | True
Compensate Outer Wall Overlaps | False
Compensate Inner Wall Overlaps | True
Minimum Wall Flow | 0 | %
Prefer Retract | False
Fill Gaps Between Walls | everywhere
Filter Out Tiny Gaps | False
Print Thin Walls | False
Horizontal Expansion | 0 | mm
Initial Layer Horizontal Expansion | 0 | mm
Hole Horizontal Expansion | 0 | mm
Z Seam Alignment | back
Z Seam Position | back
Z Seam X | 150 | mm
Z Seam Y | 300 | mm
Seam Corner Preference | z_seam_corner_weighted
Z Seam Relative | False | mm
No Skin in Z Gaps | False
Extra Skin Wall Count | 1
Enable Ironing | False
Iron Only Highest Layer | False
Ironing Pattern | zigzag
Ironing Line Spacing | 0.1 | mm
Ironing Flow | 10 | %
Ironing Inset | 0.38 | mm
Ironing Speed | 16.6667 | mm/s
Ironing Acceleration | 500 | mm/s²
Ironing Jerk | 8 | mm/s
Skin Overlap Percentage | 10 | %
Skin Overlap | 0.04 | mm
Extruder : 1 Infill
Infill Extruder | -1
Infill Density | 15 | %
Infill Line Distance | 8 | mm
Infill Pattern | cubic
Connect Infill Lines | False
Connect Infill Polygons | False
Infill Line Directions | [ ]
Infill X Offset | 0 | mm
Infill Y Offset | 0 | mm
Randomize Infill Start | False
Infill Line Multiplier | 1
Extra Infill Wall Count | 0
Cubic Subdivision Shell | 0.4 | mm
Infill Overlap Percentage | 30 | %
Infill Overlap | 0.12 | mm
Infill Wipe Distance | 0 | mm
Infill Layer Thickness | 0.28 | mm
Gradual Infill Steps | 0
Gradual Infill Step Height | 1.5 | mm
Infill Before Walls | False
Minimum Infill Area | 0 | mm²
Infill Support | False
Infill Overhang Angle | 40 | °
Skin Removal Width | 0.8 | mm
Top Skin Removal Width | 0.8 | mm
Bottom Skin Removal Width | 0.8 | mm
Skin Expand Distance | 0.8 | mm
Top Skin Expand Distance | 0.8 | mm
Bottom Skin Expand Distance | 0.8 | mm
Maximum Skin Angle for Expansion | 90 | °
Minimum Skin Width for Expansion | 0 | mm
Skin Edge Support Thickness | 0 | mm
Skin Edge Support Layers | 0
Extruder : 1 Material
Default Printing Temperature | 190 | °C
Build Volume Temperature | 28 | °C
Printing Temperature | 190 | °C
Printing Temperature Initial Layer | 190 | °C
Initial Printing Temperature | 190 | °C
Final Printing Temperature | 190 | °C
Extrusion Cool Down Speed Modifier | 0.7 | °C/s
Default Build Plate Temperature | 55 | °C
Build Plate Temperature | 55 | °C
Build Plate Temperature Initial Layer | 55 | °C
Adhesion Tendency | 0
Surface Energy | 100 | %
Shrinkage Ratio | 0 | %
Crystalline Material | False
Anti-ooze Retracted Position | -4 | mm
Anti-ooze Retraction Speed | 5 | mm/s
Break Preparation Retracted Position | -16 | mm
Break Preparation Retraction Speed | 2 | mm/s
Break Preparation Temperature | 190 | °C
Break Retracted Position | -50 | mm
Break Retraction Speed | 25 | mm/s
Break Temperature | 50 | °C
Flush Purge Speed | 0.5
Flush Purge Length | 60
End of Filament Purge Speed | 0.5
End of Filament Purge Length | 20
Maximum Park Duration | 300
No Load Move Factor | 0.9409
Flow | 100 | %
Wall Flow | 100 | %
Outer Wall Flow | 100 | %
Inner Wall(s) Flow | 100 | %
Top/Bottom Flow | 100 | %
Top Surface Skin Flow | 100 | %
Infill Flow | 100 | %
Skirt/Brim Flow | 100 | %
Support Flow | 100 | %
Support Interface Flow | 100 | %
Support Roof Flow | 100 | %
Support Floor Flow | 100 | %
Prime Tower Flow | 100 | %
Initial Layer Flow | 100 | %
Standby Temperature | 180 | °C
Extruder : 1 Speed
Print Speed | 50 | mm/s
Infill Speed | 50 | mm/s
Wall Speed | 25 | mm/s
Outer Wall Speed | 25 | mm/s
Inner Wall Speed | 25 | mm/s
Top Surface Skin Speed | 25 | mm/s
Top/Bottom Speed | 25 | mm/s
Support Speed | 25 | mm/s
Support Infill Speed | 25 | mm/s
Support Interface Speed | 25 | mm/s
Support Roof Speed | 25 | mm/s
Support Floor Speed | 25 | mm/s
Prime Tower Speed | 25 | mm/s
Travel Speed | 150 | mm/s
Initial Layer Speed | 20 | mm/s
Initial Layer Print Speed | 20 | mm/s
Initial Layer Travel Speed | 100 | mm/s
Skirt/Brim Speed | 20 | mm/s
Z Hop Speed | 5 | mm/s
Number of Slower Layers | 2
Equalize Filament Flow | False
Maximum Speed for Flow Equalization | 150 | mm/s
Enable Acceleration Control | False
Print Acceleration | 500 | mm/s²
Infill Acceleration | 500 | mm/s²
Wall Acceleration | 500 | mm/s²
Outer Wall Acceleration | 500 | mm/s²
Inner Wall Acceleration | 500 | mm/s²
Top Surface Skin Acceleration | 500 | mm/s²
Top/Bottom Acceleration | 500 | mm/s²
Support Acceleration | 500 | mm/s²
Support Infill Acceleration | 500 | mm/s²
Support Interface Acceleration | 500 | mm/s²
Support Roof Acceleration | 500 | mm/s²
Support Floor Acceleration | 500 | mm/s²
Prime Tower Acceleration | 500 | mm/s²
Travel Acceleration | 500 | mm/s²
Initial Layer Acceleration | 500 | mm/s²
Initial Layer Print Acceleration | 500 | mm/s²
Initial Layer Travel Acceleration | 500 | mm/s²
Skirt/Brim Acceleration | 500 | mm/s²
Enable Jerk Control | False
Print Jerk | 8 | mm/s
Infill Jerk | 8 | mm/s
Wall Jerk | 8 | mm/s
Outer Wall Jerk | 8 | mm/s
Inner Wall Jerk | 8 | mm/s
Top Surface Skin Jerk | 8 | mm/s
Top/Bottom Jerk | 8 | mm/s
Support Jerk | 8 | mm/s
Support Infill Jerk | 8 | mm/s
Support Interface Jerk | 8 | mm/s
Support Roof Jerk | 8 | mm/s
Support Floor Jerk | 8 | mm/s
Prime Tower Jerk | 8 | mm/s
Travel Jerk | 8 | mm/s
Initial Layer Jerk | 8 | mm/s
Initial Layer Print Jerk | 8 | mm/s
Initial Layer Travel Jerk | 8 | mm/s
Skirt/Brim Jerk | 8 | mm/s
Extruder : 1 Travel
Enable Retraction | True
Retract at Layer Change | False
Retraction Distance | 5 | mm
Retraction Speed | 45 | mm/s
Retraction Retract Speed | 45 | mm/s
Retraction Prime Speed | 45 | mm/s
Retraction Extra Prime Amount | 0 | mm³
Retraction Minimum Travel | 1.5 | mm
Maximum Retraction Count | 100
Minimum Extrusion Distance Window | 10 | mm
Limit Support Retractions | True
Combing Mode | noskin
Max Comb Distance With No Retract | 30 | mm
Retract Before Outer Wall | True
Avoid Printed Parts When Traveling | True
Avoid Supports When Traveling | True
Travel Avoid Distance | 0.625 | mm
Layer Start X | 0 | mm
Layer Start Y | 0 | mm
Z Hop When Retracted | False
Z Hop Only Over Printed Parts | False
Z Hop Height | 0.2 | mm
Z Hop After Extruder Switch | True
Z Hop After Extruder Switch Height | 0.2 | mm
Extruder : 1 Cooling
Enable Print Cooling | True
Fan Speed | 100 | %
Regular Fan Speed | 100 | %
Maximum Fan Speed | 100 | %
Regular/Maximum Fan Speed Threshold | 10 | s
Initial Fan Speed | 0 | %
Regular Fan Speed at Height | 0.84 | mm
Regular Fan Speed at Layer | 4
Minimum Layer Time | 10 | s
Minimum Speed | 10 | mm/s
Lift Head | False
Support
Generate Support | False
Support Extruder | 0
Support Infill Extruder | 0
First Layer Support Extruder | 0
Support Interface Extruder | 0
Support Roof Extruder | 0
Support Floor Extruder | 0
Support Structure | normal
Tree Support Branch Angle | 40 | °
Tree Support Branch Distance | 1 | mm
Tree Support Branch Diameter | 2 | mm
Tree Support Branch Diameter Angle | 5 | °
Tree Support Collision Resolution | 0.2 | mm
Support Placement | everywhere
Support Overhang Angle | 35 | °
Support Pattern | zigzag
Support Wall Line Count | 1
Connect Support Lines | False
Connect Support ZigZags | True
Support Density | 20 | %
Support Line Distance | 2 | mm
Initial Layer Support Line Distance | 2 | mm
Support Infill Line Directions | [ ]
Enable Support Brim | True
Support Brim Width | 4 | mm
Support Brim Line Count | 10
Support Z Distance | 0.28 | mm
Support Top Distance | 0.28 | mm
Support Bottom Distance | 0.28 | mm
Support X/Y Distance | 0.8 | mm
Support Distance Priority | xy_overrides_z
Minimum Support X/Y Distance | 0.4 | mm
Support Stair Step Height | 0.3 | mm
Support Stair Step Maximum Width | 5 | mm
Support Stair Step Minimum Slope Angle | 10 | °
Support Join Distance | 2 | mm
Support Horizontal Expansion | 0 | mm
Support Infill Layer Thickness | 0.28 | mm
Gradual Support Infill Steps | 0
Gradual Support Infill Step Height | 1 | mm
Minimum Support Area | 2 | mm²
Enable Support Interface | True
Enable Support Roof | True
Enable Support Floor | True
Support Interface Thickness | 1.12 | mm
Support Roof Thickness | 1.12 | mm
Support Floor Thickness | 1.12 | mm
Support Interface Resolution | 0.2 | mm
Support Interface Density | 33.333 | %
Support Roof Density | 33.333 | %
Support Roof Line Distance | 2.4 | mm
Support Floor Density | 33.333 | %
Support Floor Line Distance | 2.4 | mm
Support Interface Pattern | grid
Support Roof Pattern | grid
Support Floor Pattern | grid
Minimum Support Interface Area | 10 | mm²
Minimum Support Roof Area | 10 | mm²
Minimum Support Floor Area | 10 | mm²
Support Interface Horizontal Expansion | 0 | mm
Support Roof Horizontal Expansion | 0 | mm
Support Floor Horizontal Expansion | 0 | mm
Support Interface Line Directions | [ ]
Support Roof Line Directions | [ ]
Support Floor Line Directions | [ ]
Fan Speed Override | False
Supported Skin Fan Speed | 100 | %
Use Towers | False
Tower Diameter | 3 | mm
Maximum Tower-Supported Diameter | 3 | mm
Tower Roof Angle | 65 | °
Drop Down Support Mesh | True
Scene Has Support Meshes | False
Build Plate Adhesion
Enable Prime Blob | False
Extruder Prime X Position | 0 | mm
Extruder Prime Y Position | 0 | mm
Build Plate Adhesion Type | none
Build Plate Adhesion Extruder | 0
Skirt Line Count | 3
Skirt Distance | 10 | mm
Skirt/Brim Minimum Length | 250 | mm
Brim Width | 8 | mm
Brim Line Count | 20
Brim Distance | 0 | mm
Brim Replaces Support | False
Brim Only on Outside | True
Raft Extra Margin | 15 | mm
Raft Smoothing | 5 | mm
Raft Air Gap | 0.3 | mm
Initial Layer Z Overlap | 0.15 | mm
Raft Top Layers | 2
Raft Top Layer Thickness | 0.28 | mm
Raft Top Line Width | 0.4 | mm
Raft Top Spacing | 0.4 | mm
Raft Middle Thickness | 0.42 | mm
Raft Middle Line Width | 0.8 | mm
Raft Middle Spacing | 1 | mm
Raft Base Thickness | 0.336 | mm
Raft Base Line Width | 0.8 | mm
Raft Base Line Spacing | 1.6 | mm
Raft Print Speed | 25 | mm/s
Raft Top Print Speed | 25 | mm/s
Raft Middle Print Speed | 18.75 | mm/s
Raft Base Print Speed | 18.75 | mm/s
Raft Print Acceleration | 500 | mm/s²
Raft Top Print Acceleration | 500 | mm/s²
Raft Middle Print Acceleration | 500 | mm/s²
Raft Base Print Acceleration | 500 | mm/s²
Raft Print Jerk | 8 | mm/s
Raft Top Print Jerk | 8 | mm/s
Raft Middle Print Jerk | 8 | mm/s
Raft Base Print Jerk | 8 | mm/s
Raft Fan Speed | 0 | %
Raft Top Fan Speed | 0 | %
Raft Middle Fan Speed | 0 | %
Raft Base Fan Speed | 0 | %
Extruder : 1 Mesh Fixes
Union Overlapping Volumes | True
Remove All Holes | False
Extensive Stitching | False
Keep Disconnected Faces | False
Merged Meshes Overlap | 0.15 | mm
Remove Mesh Intersection | False
Alternate Mesh Removal | True
Remove Empty First Layers | True
Maximum Resolution | 0.05 | mm
Maximum Travel Resolution | 0.05 | mm
Maximum Deviation | 0.025 | mm
Special Modes
Print Sequence | all_at_once
Infill Mesh | False
Mesh Processing Rank | 0
Cutting Mesh | False
Mold | False
Minimal Mold Width | 5 | mm
Mold Roof Height | 0.5 | mm
Mold Angle | 40 | °
Support Mesh | False
Anti Overhang Mesh | False
Surface Mode | normal
Spiralize Outer Contour | False
Smooth Spiralized Contours | True
Relative Extrusion | False
Experimental
Slicing Tolerance | middle
Top Surface Skin Line Width | 0.4 | mm
Top Surface Skin Pattern | lines
Top Surface Skin Line Directions | [ ]
Infill Travel Optimization | False
Auto Temperature | False
Flow Temperature Graph | [[3.5,200],[7.0,240]] | [[mm³,°C]]
Minimum Polygon Circumference | 1 | mm
Break Up Support In Chunks | False
Support Chunk Size | 20 | mm
Support Chunk Line Count | 10
Enable Draft Shield | False
Draft Shield X/Y Distance | 10 | mm
Draft Shield Limitation | full
Draft Shield Height | 10 | mm
Make Overhang Printable | False
Maximum Model Angle | 50 | °
Enable Coasting | False
Coasting Volume | 0.064 | mm³
Minimum Volume Before Coasting | 0.8 | mm³
Coasting Speed | 90 | %
Cross 3D Pocket Size | 8 | mm
Cross Infill Density Image
Cross Fill Density Image for Support
Enable Conical Support | False
Conical Support Angle | 30 | °
Conical Support Minimum Width | 5 | mm
Fuzzy Skin | False
Fuzzy Skin Outside Only | False
Fuzzy Skin Thickness | 0.3 | mm
Fuzzy Skin Density | 1.25 | 1/mm
Fuzzy Skin Point Distance | 0.8 | mm
Flow Rate Compensation Max Extrusion Offset | 0 | mm
Flow Rate Compensation Factor | 100 | %
Wire Printing | False
WP Connection Height | 3 | mm
WP Roof Inset Distance | 3 | mm
WP Speed | 5 | mm/s
WP Bottom Printing Speed | 5 | mm/s
WP Upward Printing Speed | 5 | mm/s
WP Downward Printing Speed | 5 | mm/s
WP Horizontal Printing Speed | 5 | mm/s
WP Flow | 100 | %
WP Connection Flow | 100 | %
WP Flat Flow | 100 | %
WP Top Delay | 0 | s
WP Bottom Delay | 0 | s
WP Flat Delay | 0.1 | s
WP Ease Upward | 0.3 | mm
WP Knot Size | 0.6 | mm
WP Fall Down | 0.5 | mm
WP Drag Along | 0.6 | mm
WP Strategy | compensate
WP Straighten Downward Lines | 20 | %
WP Roof Fall Down | 2 | mm
WP Roof Drag Along | 0.8 | mm
WP Roof Outer Delay | 0.2 | s
WP Nozzle Clearance | 1 | mm
Use Adaptive Layers | False
Adaptive Layers Maximum Variation | 0.04 | mm
Adaptive Layers Variation Step Size | 0.04 | mm
Adaptive Layers Topography Size | 0.2 | mm
Overhanging Wall Angle | 90 | °
Overhanging Wall Speed | 100 | %
Enable Bridge Settings | False
Minimum Bridge Wall Length | 5 | mm
Bridge Skin Support Threshold | 50 | %
Bridge Sparse Infill Max Density | 0 | %
Bridge Wall Coasting | 100 | %
Bridge Wall Speed | 12.5 | mm/s
Bridge Wall Flow | 50 | %
Bridge Skin Speed | 12.5 | mm/s
Bridge Skin Flow | 60 | %
Bridge Skin Density | 100 | %
Bridge Fan Speed | 100 | %
Bridge Has Multiple Layers | True
Bridge Second Skin Speed | 12.5 | mm/s
Bridge Second Skin Flow | 100 | %
Bridge Second Skin Density | 75 | %
Bridge Second Skin Fan Speed | 0 | %
Bridge Third Skin Speed | 12.5 | mm/s
Bridge Third Skin Flow | 110 | %
Bridge Third Skin Density | 80 | %
Bridge Third Skin Fan Speed | 0 | %
Wipe Nozzle Between Layers | False
Material Volume Between Wipes | 10 | mm³
Wipe Retraction Enable | True
Wipe Retraction Distance | 5 | mm
Wipe Retraction Extra Prime Amount | 0 | mm³
Wipe Retraction Speed | 45 | mm/s
Wipe Retraction Retract Speed | 45 | mm/s
Wipe Retraction Prime Speed | 45 | mm/s
Wipe Pause | 0 | s
Wipe Z Hop | False
Wipe Z Hop Height | 0.2 | mm
Wipe Hop Speed | 5 | mm/s
Wipe Brush X Position | 100 | mm
Wipe Repeat Count | 5
Wipe Move Distance | 20 | mm
Small Hole Max Size | 0 | mm
Small Feature Max Length | 0 | mm
Small Feature Speed | 50 | %
Small Feature Initial Layer Speed | 50 | %
Machine
Machine Type | Creality CR-10S
Show Machine Variants | False

Start G-code

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

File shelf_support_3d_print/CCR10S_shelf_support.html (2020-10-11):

# Print settings

Visible settings:

Job Name | CCR10S_shelf_support
Date | 11/10/2020 19:04:00
Os | Linux #1 SMP PREEMPT Thu, 17 Sep 2020 18:01:06 +0000
Cura Version | 4.7.1
Profile | empty
Quality | Dynamic Quality
Material Extruder : 1 | PLA
Material estimation | 139.5 g
Printing Time | 1 d 0 h 18 mn
Extruder : 1 Quality
Layer Height | 0.16 | mm
Initial Layer Height | 0.2 | mm
Line Width | 0.4 | mm
Wall Line Width | 0.4 | mm
Outer Wall Line Width | 0.4 | mm
Inner Wall(s) Line Width | 0.4 | mm
Top/Bottom Line Width | 0.4 | mm
Infill Line Width | 0.4 | mm
Skirt/Brim Line Width | 0.4 | mm
Support Line Width | 0.4 | mm
Support Interface Line Width | 0.4 | mm
Support Roof Line Width | 0.4 | mm
Support Floor Line Width | 0.4 | mm
Prime Tower Line Width | 0.4 | mm
Initial Layer Line Width | 100 | %
Extruder : 1 Shell
Wall Extruder | -1
Outer Wall Extruder | -1
Inner Wall Extruder | -1
Wall Thickness | 1.2 | mm
Wall Line Count | 3
Outer Wall Wipe Distance | 0 | mm
Top Surface Skin Extruder | -1
Top Surface Skin Layers | 0
Top/Bottom Extruder | -1
Top/Bottom Thickness | 0.84 | mm
Top Thickness | 0.84 | mm
Top Layers | 6
Bottom Thickness | 0.84 | mm
Bottom Layers | 6
Initial Bottom Layers | 6
Top/Bottom Pattern | lines
Bottom Pattern Initial Layer | lines
Connect Top/Bottom Polygons | False
Top/Bottom Line Directions | [ ]
Outer Wall Inset | 0 | mm
Optimize Wall Printing Order | True
Outer Before Inner Walls | False
Alternate Extra Wall | False
Compensate Wall Overlaps | True
Compensate Outer Wall Overlaps | False
Compensate Inner Wall Overlaps | True
Minimum Wall Flow | 0 | %
Prefer Retract | False
Fill Gaps Between Walls | everywhere
Filter Out Tiny Gaps | False
Print Thin Walls | False
Horizontal Expansion | 0 | mm
Initial Layer Horizontal Expansion | 0 | mm
Hole Horizontal Expansion | 0 | mm
Z Seam Alignment | back
Z Seam Position | back
Z Seam X | 150 | mm
Z Seam Y | 300 | mm
Seam Corner Preference | z_seam_corner_weighted
Z Seam Relative | False | mm
No Skin in Z Gaps | False
Extra Skin Wall Count | 1
Enable Ironing | False
Iron Only Highest Layer | False
Ironing Pattern | zigzag
Ironing Line Spacing | 0.1 | mm
Ironing Flow | 10 | %
Ironing Inset | 0.38 | mm
Ironing Speed | 16.6667 | mm/s
Ironing Acceleration | 500 | mm/s²
Ironing Jerk | 8 | mm/s
Skin Overlap Percentage | 10 | %
Skin Overlap | 0.04 | mm
Extruder : 1 Infill
Infill Extruder | -1
Infill Density | 20 | %
Infill Line Distance | 6 | mm
Infill Pattern | cubic
Connect Infill Lines | False
Connect Infill Polygons | False
Infill Line Directions | [ ]
Infill X Offset | 0 | mm
Infill Y Offset | 0 | mm
Randomize Infill Start | False
Infill Line Multiplier | 1
Extra Infill Wall Count | 0
Cubic Subdivision Shell | 0.4 | mm
Infill Overlap Percentage | 30 | %
Infill Overlap | 0.12 | mm
Infill Wipe Distance | 0 | mm
Infill Layer Thickness | 0.16 | mm
Gradual Infill Steps | 0
Gradual Infill Step Height | 1.5 | mm
Infill Before Walls | False
Minimum Infill Area | 0 | mm²
Infill Support | False
Infill Overhang Angle | 40 | °
Skin Removal Width | 1.2 | mm
Top Skin Removal Width | 1.2 | mm
Bottom Skin Removal Width | 1.2 | mm
Skin Expand Distance | 1.2 | mm
Top Skin Expand Distance | 1.2 | mm
Bottom Skin Expand Distance | 1.2 | mm
Maximum Skin Angle for Expansion | 90 | °
Minimum Skin Width for Expansion | 0 | mm
Skin Edge Support Thickness | 0 | mm
Skin Edge Support Layers | 0
Extruder : 1 Material
Default Printing Temperature | 200 | °C
Build Volume Temperature | 28 | °C
Printing Temperature | 200 | °C
Printing Temperature Initial Layer | 200 | °C
Initial Printing Temperature | 200 | °C
Final Printing Temperature | 200 | °C
Extrusion Cool Down Speed Modifier | 0.7 | °C/s
Default Build Plate Temperature | 70 | °C
Build Plate Temperature | 70 | °C
Build Plate Temperature Initial Layer | 70 | °C
Adhesion Tendency | 0
Surface Energy | 100 | %
Shrinkage Ratio | 0 | %
Crystalline Material | False
Anti-ooze Retracted Position | -4 | mm
Anti-ooze Retraction Speed | 5 | mm/s
Break Preparation Retracted Position | -16 | mm
Break Preparation Retraction Speed | 2 | mm/s
Break Preparation Temperature | 200 | °C
Break Retracted Position | -50 | mm
Break Retraction Speed | 25 | mm/s
Break Temperature | 50 | °C
Flush Purge Speed | 0.5
Flush Purge Length | 60
End of Filament Purge Speed | 0.5
End of Filament Purge Length | 20
Maximum Park Duration | 300
No Load Move Factor | 0.9409
Flow | 100 | %
Wall Flow | 100 | %
Outer Wall Flow | 100 | %
Inner Wall(s) Flow | 100 | %
Top/Bottom Flow | 100 | %
Top Surface Skin Flow | 100 | %
Infill Flow | 100 | %
Skirt/Brim Flow | 100 | %
Support Flow | 100 | %
Support Interface Flow | 100 | %
Support Roof Flow | 100 | %
Support Floor Flow | 100 | %
Prime Tower Flow | 100 | %
Initial Layer Flow | 100 | %
Standby Temperature | 180 | °C
Extruder : 1 Speed
Print Speed | 50 | mm/s
Infill Speed | 50 | mm/s
Wall Speed | 25 | mm/s
Outer Wall Speed | 25 | mm/s
Inner Wall Speed | 25 | mm/s
Top Surface Skin Speed | 25 | mm/s
Top/Bottom Speed | 25 | mm/s
Support Speed | 25 | mm/s
Support Infill Speed | 25 | mm/s
Support Interface Speed | 25 | mm/s
Support Roof Speed | 25 | mm/s
Support Floor Speed | 25 | mm/s
Prime Tower Speed | 25 | mm/s
Travel Speed | 150 | mm/s
Initial Layer Speed | 20 | mm/s
Initial Layer Print Speed | 20 | mm/s
Initial Layer Travel Speed | 100 | mm/s
Skirt/Brim Speed | 20 | mm/s
Z Hop Speed | 5 | mm/s
Number of Slower Layers | 2
Equalize Filament Flow | False
Maximum Speed for Flow Equalization | 150 | mm/s
Enable Acceleration Control | False
Print Acceleration | 500 | mm/s²
Infill Acceleration | 500 | mm/s²
Wall Acceleration | 500 | mm/s²
Outer Wall Acceleration | 500 | mm/s²
Inner Wall Acceleration | 500 | mm/s²
Top Surface Skin Acceleration | 500 | mm/s²
Top/Bottom Acceleration | 500 | mm/s²
Support Acceleration | 500 | mm/s²
Support Infill Acceleration | 500 | mm/s²
Support Interface Acceleration | 500 | mm/s²
Support Roof Acceleration | 500 | mm/s²
Support Floor Acceleration | 500 | mm/s²
Prime Tower Acceleration | 500 | mm/s²
Travel Acceleration | 500 | mm/s²
Initial Layer Acceleration | 500 | mm/s²
Initial Layer Print Acceleration | 500 | mm/s²
Initial Layer Travel Acceleration | 500 | mm/s²
Skirt/Brim Acceleration | 500 | mm/s²
Enable Jerk Control | False
Print Jerk | 8 | mm/s
Infill Jerk | 8 | mm/s
Wall Jerk | 8 | mm/s
Outer Wall Jerk | 8 | mm/s
Inner Wall Jerk | 8 | mm/s
Top Surface Skin Jerk | 8 | mm/s
Top/Bottom Jerk | 8 | mm/s
Support Jerk | 8 | mm/s
Support Infill Jerk | 8 | mm/s
Support Interface Jerk | 8 | mm/s
Support Roof Jerk | 8 | mm/s
Support Floor Jerk | 8 | mm/s
Prime Tower Jerk | 8 | mm/s
Travel Jerk | 8 | mm/s
Initial Layer Jerk | 8 | mm/s
Initial Layer Print Jerk | 8 | mm/s
Initial Layer Travel Jerk | 8 | mm/s
Skirt/Brim Jerk | 8 | mm/s
Extruder : 1 Travel
Enable Retraction | True
Retract at Layer Change | False
Retraction Distance | 5 | mm
Retraction Speed | 45 | mm/s
Retraction Retract Speed | 45 | mm/s
Retraction Prime Speed | 45 | mm/s
Retraction Extra Prime Amount | 0 | mm³
Retraction Minimum Travel | 1.5 | mm
Maximum Retraction Count | 100
Minimum Extrusion Distance Window | 10 | mm
Limit Support Retractions | True
Combing Mode | noskin
Max Comb Distance With No Retract | 30 | mm
Retract Before Outer Wall | True
Avoid Printed Parts When Traveling | True
Avoid Supports When Traveling | True
Travel Avoid Distance | 0.625 | mm
Layer Start X | 0 | mm
Layer Start Y | 0 | mm
Z Hop When Retracted | False
Z Hop Only Over Printed Parts | False
Z Hop Height | 0.2 | mm
Z Hop After Extruder Switch | True
Z Hop After Extruder Switch Height | 0.2 | mm
Extruder : 1 Cooling
Enable Print Cooling | True
Fan Speed | 100 | %
Regular Fan Speed | 100 | %
Maximum Fan Speed | 100 | %
Regular/Maximum Fan Speed Threshold | 10 | s
Initial Fan Speed | 0 | %
Regular Fan Speed at Height | 0.52 | mm
Regular Fan Speed at Layer | 4
Minimum Layer Time | 10 | s
Minimum Speed | 10 | mm/s
Lift Head | False
Support
Generate Support | False
Support Extruder | 0
Support Infill Extruder | 0
First Layer Support Extruder | 0
Support Interface Extruder | 0
Support Roof Extruder | 0
Support Floor Extruder | 0
Support Structure | normal
Tree Support Branch Angle | 40 | °
Tree Support Branch Distance | 1 | mm
Tree Support Branch Diameter | 2 | mm
Tree Support Branch Diameter Angle | 5 | °
Tree Support Collision Resolution | 0.2 | mm
Support Placement | everywhere
Support Overhang Angle | 51 | °
Support Pattern | zigzag
Support Wall Line Count | 1
Connect Support Lines | False
Connect Support ZigZags | True
Support Density | 20 | %
Support Line Distance | 2 | mm
Initial Layer Support Line Distance | 2 | mm
Support Infill Line Directions | [ ]
Enable Support Brim | True
Support Brim Width | 4 | mm
Support Brim Line Count | 10
Support Z Distance | 0.16 | mm
Support Top Distance | 0.16 | mm
Support Bottom Distance | 0.16 | mm
Support X/Y Distance | 0.8 | mm
Support Distance Priority | xy_overrides_z
Minimum Support X/Y Distance | 0.4 | mm
Support Stair Step Height | 0.3 | mm
Support Stair Step Maximum Width | 5 | mm
Support Stair Step Minimum Slope Angle | 10 | °
Support Join Distance | 2 | mm
Support Horizontal Expansion | 0 | mm
Support Infill Layer Thickness | 0.16 | mm
Gradual Support Infill Steps | 0
Gradual Support Infill Step Height | 1 | mm
Minimum Support Area | 2 | mm²
Enable Support Interface | True
Enable Support Roof | True
Enable Support Floor | True
Support Interface Thickness | 0.96 | mm
Support Roof Thickness | 0.96 | mm
Support Floor Thickness | 0.96 | mm
Support Interface Resolution | 0.2 | mm
Support Interface Density | 33.333 | %
Support Roof Density | 33.333 | %
Support Roof Line Distance | 2.4 | mm
Support Floor Density | 33.333 | %
Support Floor Line Distance | 2.4 | mm
Support Interface Pattern | grid
Support Roof Pattern | grid
Support Floor Pattern | grid
Minimum Support Interface Area | 10 | mm²
Minimum Support Roof Area | 10 | mm²
Minimum Support Floor Area | 10 | mm²
Support Interface Horizontal Expansion | 0 | mm
Support Roof Horizontal Expansion | 0 | mm
Support Floor Horizontal Expansion | 0 | mm
Support Interface Line Directions | [ ]
Support Roof Line Directions | [ ]
Support Floor Line Directions | [ ]
Fan Speed Override | False
Supported Skin Fan Speed | 100 | %
Use Towers | False
Tower Diameter | 3 | mm
Maximum Tower-Supported Diameter | 3 | mm
Tower Roof Angle | 65 | °
Drop Down Support Mesh | True
Scene Has Support Meshes | False
Build Plate Adhesion
Enable Prime Blob | False
Extruder Prime X Position | 0 | mm
Extruder Prime Y Position | 0 | mm
Build Plate Adhesion Type | none
Build Plate Adhesion Extruder | 0
Skirt Line Count | 3
Skirt Distance | 10 | mm
Skirt/Brim Minimum Length | 250 | mm
Brim Width | 8 | mm
Brim Line Count | 20
Brim Distance | 0 | mm
Brim Replaces Support | False
Brim Only on Outside | True
Raft Extra Margin | 15 | mm
Raft Smoothing | 5 | mm
Raft Air Gap | 0.3 | mm
Initial Layer Z Overlap | 0.15 | mm
Raft Top Layers | 2
Raft Top Layer Thickness | 0.16 | mm
Raft Top Line Width | 0.4 | mm
Raft Top Spacing | 0.4 | mm
Raft Middle Thickness | 0.24 | mm
Raft Middle Line Width | 0.8 | mm
Raft Middle Spacing | 1 | mm
Raft Base Thickness | 0.24 | mm
Raft Base Line Width | 0.8 | mm
Raft Base Line Spacing | 1.6 | mm
Raft Print Speed | 25 | mm/s
Raft Top Print Speed | 25 | mm/s
Raft Middle Print Speed | 18.75 | mm/s
Raft Base Print Speed | 18.75 | mm/s
Raft Print Acceleration | 500 | mm/s²
Raft Top Print Acceleration | 500 | mm/s²
Raft Middle Print Acceleration | 500 | mm/s²
Raft Base Print Acceleration | 500 | mm/s²
Raft Print Jerk | 8 | mm/s
Raft Top Print Jerk | 8 | mm/s
Raft Middle Print Jerk | 8 | mm/s
Raft Base Print Jerk | 8 | mm/s
Raft Fan Speed | 0 | %
Raft Top Fan Speed | 0 | %
Raft Middle Fan Speed | 0 | %
Raft Base Fan Speed | 0 | %
Extruder : 1 Mesh Fixes
Union Overlapping Volumes | True
Remove All Holes | False
Extensive Stitching | False
Keep Disconnected Faces | False
Merged Meshes Overlap | 0.15 | mm
Remove Mesh Intersection | False
Alternate Mesh Removal | True
Remove Empty First Layers | True
Maximum Resolution | 0.05 | mm
Maximum Travel Resolution | 0.05 | mm
Maximum Deviation | 0.025 | mm
Special Modes
Print Sequence | all_at_once
Infill Mesh | False
Mesh Processing Rank | 0
Cutting Mesh | False
Mold | False
Minimal Mold Width | 5 | mm
Mold Roof Height | 0.5 | mm
Mold Angle | 40 | °
Support Mesh | False
Anti Overhang Mesh | False
Surface Mode | normal
Spiralize Outer Contour | False
Smooth Spiralized Contours | True
Relative Extrusion | False
Experimental
Slicing Tolerance | middle
Top Surface Skin Line Width | 0.4 | mm
Top Surface Skin Pattern | lines
Top Surface Skin Line Directions | [ ]
Infill Travel Optimization | False
Auto Temperature | False
Flow Temperature Graph | [[3.5,200],[7.0,240]] | [[mm³,°C]]
Minimum Polygon Circumference | 1 | mm
Break Up Support In Chunks | False
Support Chunk Size | 20 | mm
Support Chunk Line Count | 10
Enable Draft Shield | False
Draft Shield X/Y Distance | 10 | mm
Draft Shield Limitation | full
Draft Shield Height | 10 | mm
Make Overhang Printable | False
Maximum Model Angle | 50 | °
Enable Coasting | False
Coasting Volume | 0.064 | mm³
Minimum Volume Before Coasting | 0.8 | mm³
Coasting Speed | 90 | %
Cross 3D Pocket Size | 6 | mm
Cross Infill Density Image
Cross Fill Density Image for Support
Enable Conical Support | False
Conical Support Angle | 30 | °
Conical Support Minimum Width | 5 | mm
Fuzzy Skin | False
Fuzzy Skin Outside Only | False
Fuzzy Skin Thickness | 0.3 | mm
Fuzzy Skin Density | 1.25 | 1/mm
Fuzzy Skin Point Distance | 0.8 | mm
Flow Rate Compensation Max Extrusion Offset | 0 | mm
Flow Rate Compensation Factor | 100 | %
Wire Printing | False
WP Connection Height | 3 | mm
WP Roof Inset Distance | 3 | mm
WP Speed | 5 | mm/s
WP Bottom Printing Speed | 5 | mm/s
WP Upward Printing Speed | 5 | mm/s
WP Downward Printing Speed | 5 | mm/s
WP Horizontal Printing Speed | 5 | mm/s
WP Flow | 100 | %
WP Connection Flow | 100 | %
WP Flat Flow | 100 | %
WP Top Delay | 0 | s
WP Bottom Delay | 0 | s
WP Flat Delay | 0.1 | s
WP Ease Upward | 0.3 | mm
WP Knot Size | 0.6 | mm
WP Fall Down | 0.5 | mm
WP Drag Along | 0.6 | mm
WP Strategy | compensate
WP Straighten Downward Lines | 20 | %
WP Roof Fall Down | 2 | mm
WP Roof Drag Along | 0.8 | mm
WP Roof Outer Delay | 0.2 | s
WP Nozzle Clearance | 1 | mm
Use Adaptive Layers | true
Adaptive Layers Maximum Variation | 0.04 | mm
Adaptive Layers Variation Step Size | 0.04 | mm
Adaptive Layers Topography Size | 0.2 | mm
Overhanging Wall Angle | 90 | °
Overhanging Wall Speed | 100 | %
Enable Bridge Settings | False
Minimum Bridge Wall Length | 5 | mm
Bridge Skin Support Threshold | 50 | %
Bridge Sparse Infill Max Density | 0 | %
Bridge Wall Coasting | 100 | %
Bridge Wall Speed | 12.5 | mm/s
Bridge Wall Flow | 50 | %
Bridge Skin Speed | 12.5 | mm/s
Bridge Skin Flow | 60 | %
Bridge Skin Density | 100 | %
Bridge Fan Speed | 100 | %
Bridge Has Multiple Layers | True
Bridge Second Skin Speed | 12.5 | mm/s
Bridge Second Skin Flow | 100 | %
Bridge Second Skin Density | 75 | %
Bridge Second Skin Fan Speed | 0 | %
Bridge Third Skin Speed | 12.5 | mm/s
Bridge Third Skin Flow | 110 | %
Bridge Third Skin Density | 80 | %
Bridge Third Skin Fan Speed | 0 | %
Wipe Nozzle Between Layers | False
Material Volume Between Wipes | 10 | mm³
Wipe Retraction Enable | True
Wipe Retraction Distance | 5 | mm
Wipe Retraction Extra Prime Amount | 0 | mm³
Wipe Retraction Speed | 45 | mm/s
Wipe Retraction Retract Speed | 45 | mm/s
Wipe Retraction Prime Speed | 45 | mm/s
Wipe Pause | 0 | s
Wipe Z Hop | False
Wipe Z Hop Height | 0.2 | mm
Wipe Hop Speed | 5 | mm/s
Wipe Brush X Position | 100 | mm
Wipe Repeat Count | 5
Wipe Move Distance | 20 | mm
Small Hole Max Size | 0 | mm
Small Feature Max Length | 0 | mm
Small Feature Speed | 50 | %
Small Feature Initial Layer Speed | 50 | %
Machine
Machine Type | Creality CR-10S
Show Machine Variants | False

Start G-code

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

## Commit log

2020-09-23 WIP workbench
    [config.scad, leg.scad, rabbeted_horizontal_plate.scad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]
2020-09-23 Commit initial work on workbench from last night
    [config.scad, desktop.scad, leg.scad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]
2020-09-23 initial design
    [hutch_shelf.scad, table.scad]
2020-09-24 add explode module from https://gist.github.com/damccull/1a1df5e785e56daf53e0d7b7d8ff219e
    [explode.scad]
2020-09-24 move module
    [explode.scad]
2020-09-24 design should be complete
    [config.scad, desktop_support.scad, long_horizontal_plate.scad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]
2020-09-24 drop shelves a bit
    [config.scad]
2020-09-25 bill of materials
    [config.scad]
2020-09-26 fix coloring by component
    [config.scad, desktop_support.scad, hutch_shelf_support.scad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]
2020-10-03 add 3d printer
    [table.scad]
2020-10-04 add MFC printer
    [printer.scad, printer_thingiverse_494241.stl, table.scad]
2020-10-04 add shelf for 3d printer power supply
    [config.scad, leg.scad, table.scad]
2020-10-04 pegboard color
    [table.scad]
2020-10-05 WIP shelf supports - need screw holes
    [shelf_support.scad]
2020-10-05 WIP shelf supports
    [shelf_support.scad]
2020-10-05 shelf supports
    [shelf_support.scad, table.scad]
2020-10-05 simplify modules by not passing config vars
    [config.scad, desktop.scad, desktop_support.scad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]
2020-10-05 parts shelves
    [config.scad, table.scad]
2020-10-05 WIP fixing exploded view
    [desktop_support.scad, hutch_shelf_support.scad, leg.scad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]
2020-10-06 screw holes in shelf support
    [shelf_support.scad]
2020-10-06 test shelf support at parts_support_height = 1.5
    [shelf_support.scad, shelf_support_test.stl]
2020-10-06 shelf support test sliced at 20% infill
    [CCR10S_shelf_support_test.3mf]
2020-10-06 flip top shelf supports for more vertical space
    [config.scad, leg.scad, long_horizontal_plate.scad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]
2020-10-06 Fix shelf supports
    [config.scad, shelf_support.scad, table.scad]
2020-10-06 v2 shelf support test
    [CCR10S_shelf_support_test.3mf, config.scad, shelf_support_test.stl]
2020-10-06 full height shelf support
    [config.scad]
2020-10-06 individual_components directory
    [CCR10S_shelf_support_test.3mf, shelf_support.scad, shelf_support_test.stl]
2020-10-06 add echos for BOM
    [desktop.scad, desktop_support.scad, hutch_shelf.scad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]
2020-10-06 build BOM
2020-10-07 individual components for each manufactured piece
    [leg_NOTcenter_NOTinner_NOTleft.scad, leg_NOTcenter_NOTinner_left.scad, leg_NOTcenter_inner_NOTleft.scad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]
2020-10-07 STL for individual components
    [desktop.scad, desktop.stl, desktop_support.scad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]
2020-10-07 create test directory
    [CCR10S_shelf_support_test.3mf, shelf_support.scad, shelf_support_test.stl]
2020-10-07 test for the size of the shelf support back
    [CCR10S_shelf_support_back.3mf, shelf_support_back.scad, shelf_support_back.stl]
2020-10-08 regenerate BOM
    [desktop.scad, desktop_support.scad, hutch_shelf.scad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]
2020-10-08 WIP dimensioned drawings
    [hutch_shelf_support.scad, rotated_view.scad]
2020-10-08 individual components shouldn't be committed
    [desktop.scad, desktop.stl, desktop_support.scad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]
2020-10-09 bump shelf supports to 11.5" deep; render
    [config.scad, shelf_support.stl]
2020-10-09 WIP per-component printable views
2020-10-10 minor fixes
    [rotated_view.scad, table.scad]
2020-10-10 fixes for per-component views
    [hutch_shelf.scad, lower_shelf.scad, table.scad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]
2020-10-10 more per-component view fixes
    [desktop.scad, table.scad, upper_side_tieA.scad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]
2020-10-11 finish per-component views
    [rotated_view.scad]
2020-10-11 Add code to render exploded views
    [table.scad]
2020-10-11 re-render and slice shelf support for Inland Gray PLA+ at 20% infill; need 6 of them, each taking 24h8m and 140g/47m filament
    [CCR10S_shelf_support.3mf, shelf_support.stl]
2020-10-12 fix bug in upper_side_tie models
    [upper_side_tieA.scad, upper_side_tieB.scad]
2020-10-13 render STL of framing
    [framing.stl]
2020-10-15 slice shelf support for low quality test build
    [CCR10S_shelf_support_low_quality_15pct_infill.3mf]
2020-10-15 Previous slice of this was completely broken; re-slice correctly
    [CCR10S_shelf_support_low_quality_15pct_infill.3mf]
2020-10-17 shelf support - move screw holes in to 1" from each side
    [shelf_support.scad, shelf_support.stl]
2020-10-17 re-slice shelf supports
    [CCR10S_shelf_support_HatchboxPureWhitePLA_15pctInfill.3mf]
